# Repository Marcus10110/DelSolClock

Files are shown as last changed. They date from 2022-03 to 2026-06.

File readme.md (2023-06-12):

# Del Sol Clock

This is a project to replace the clock in my car with an ESP32 and a small display.

The replacement clock screen will display time, the currently playing music, and iOS notifications.

Bluetooth low energy is used to communicate with a phone.
Note, some services should support any BLE phone, for example the current time service. However the Apple Media Service and the notification service only support iOS.

## Features

### Apple Media Service

This displays the current playback information from the iPhone. It doesn't currently support playback controls (e.g. next/previous track).

[Apple Documentation.](https://developer.apple.com/library/archive/documentation/CoreBluetooth/Reference/AppleMediaService_Reference/Specification/Specification.html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)

Special thanks to the following examples. As far as I can tell, this hasn't been implemented using the [Arduino ESP32 board library](https://github.com/espressif/arduino-esp32) before.

- [James Hudson's Apple Notification Center Service](https://github.com/Smartphone-Companions/ESP32-ANCS-Notifications/blob/master/src/ancs_ble_client.cpp) This example finally showed how to solicit services using the Arduino ESP32 library, which is not built-in.
- [John Park's Adafruit Guide to the Apple Media Service Display](https://learn.adafruit.com/now-playing-bluetooth-apple-media-service-display/apple-music-service) This was the first working example I could find. Written in CircutPython.
- [Moddable's Apple Media Service example](https://github.com/Moddable-OpenSource/moddable/blob/6d7f33f8f318663bd5ba8d6ca6536443d42e68ea/modules/network/ble/ams-client/amsclient.js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) This was another good example, written in javascript.

### Current Time Service

This gets the current time.

[Current Time Service Documentation](https://www.bluetooth.com/specifications/specs/current-time-service-1-1/)

Note, the documentation is split over several PDFs. See CurrentTimeService.cpp for more documentation links.

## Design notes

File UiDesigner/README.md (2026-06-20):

# UiDesigner

Renders the Del Sol Clock's screens to BMP on the desktop, so screen UI can be
developed and reviewed without the ESP32.

The screen code is **shared** with the firmware: it lives in
`../firmware/lib/display/` and is compiled here against the real Adafruit GFX
library, so the rendered output is pixel-identical to the device.

## Render the screens

```powershell
pwsh -File tools/generate_on_save.ps1
```

Outputs to `out/`: one BMP per screen plus `all_screens.bmp` (a labeled grid of
all of them). Requires Visual Studio 2022 (C++ toolchain) and `ninja.exe` in
`.deps/`.

## Iterate

Open the **repo root** in VS Code and install the *Run on Save*
(`emeraldwalk.RunOnSave`) extension. Saving any screen source under
`firmware/lib/display/` or `runner/` auto-rebuilds and re-renders.

- Screen drawing code: `../firmware/lib/display/src/<group>_screen.cpp`
- Sample data each screen renders with: `../firmware/lib/display/src/demo_screens.cpp`
- BMP assets the screens reference: `data/`

## Manual build

```powershell
cmake -S . -B build -G "Visual Studio 17 2022" -A x64
cmake --build build --config Release --target render_screens
./build/Release/render_screens.exe   # run from this directory (resolves data/ + out/)
```

## Layout

- `runner/` — entry point + the desktop (file-backed) image loader
- `tools/` — build/configure/render scripts (`vsenv.ps1` sets up the VS env)
- `data/` — BMP assets for rendering
- `out/`, `build/`, `.deps/`, `reference/` — generated/local (gitignored)

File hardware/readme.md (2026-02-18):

# Hardware

The Del Sol Clock PCBs are designed to be direct replacements for the stock clock PCBs found in the original dash clock.

There are two PCBs in the clock housing. The front PCB, which contains pretty everything, and a rear PCB, which is largely responsible for the electrical connections to the car.

The two PCBs are designed with KiCad. The front PCB is located in the `./DelSolClock` directory, and the rear PCB is located in `./DelSolClock-Rear` directory.

## Front PCB

Schematic:

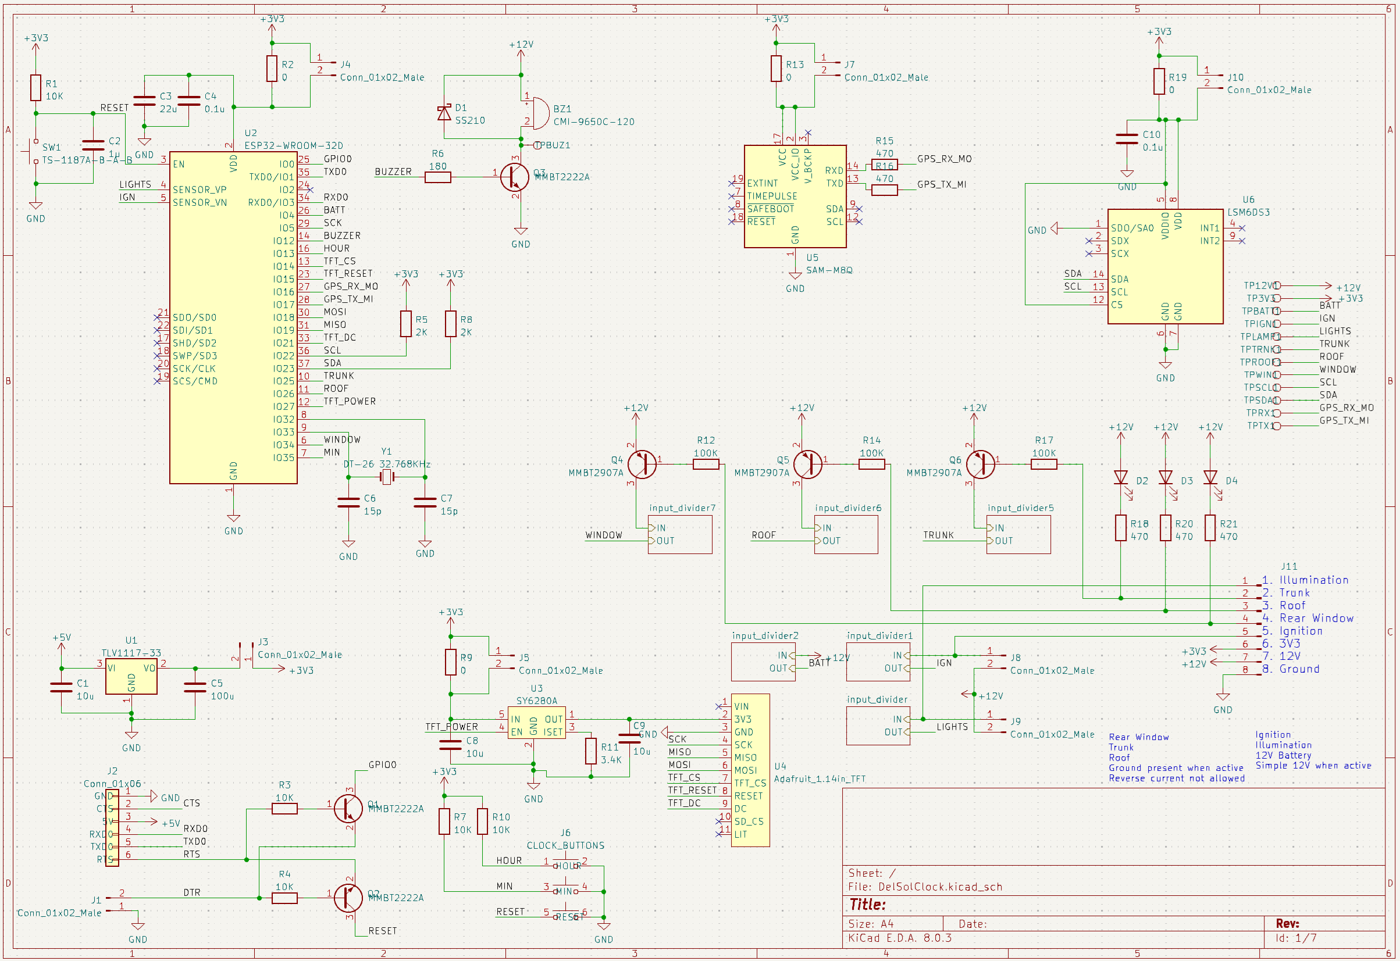
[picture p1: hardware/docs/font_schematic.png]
front schematic


Divider Circuit:

This divider circuit is used to shift the 12V signal down to 3.3V without engaging over voltage protection. It uses a ~3.6 volt Zener diode to clamp the voltage, which is preferred over regular rail clamps to prevent damage if the supply voltage is not present when a 12V input is applied.

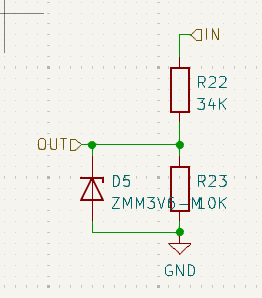
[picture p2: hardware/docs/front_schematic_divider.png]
voltage divider circuit


PCB:

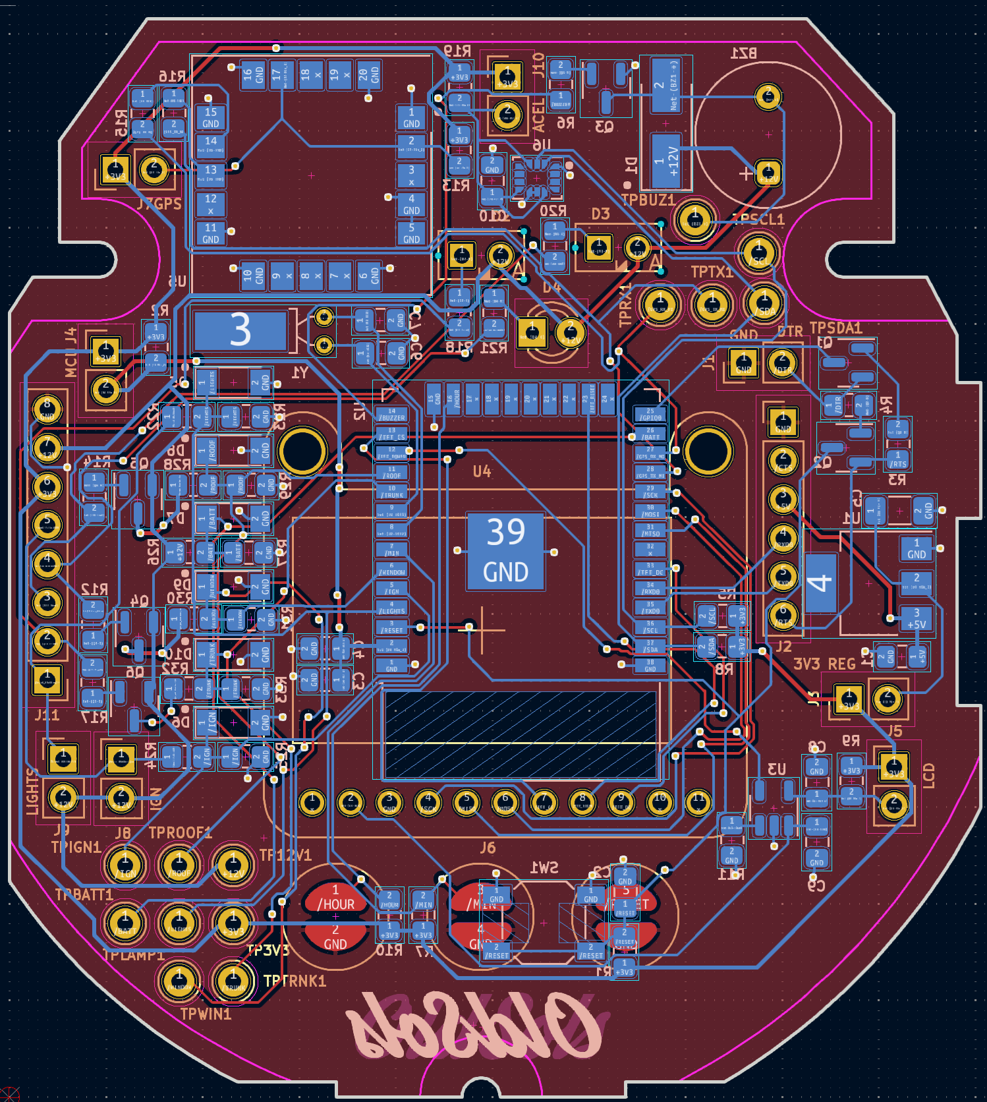
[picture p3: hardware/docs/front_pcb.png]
front PCB layout


## Rear PCB

The rear PCB contains a 12V to 3.3V buck converter module, to provide power to the front PCB, and routes all the car IO signals to the front PCB.

The front PCB is connected to the read PCB with a short 8 pin ribbon cable.

The rear PCB also contains diodes for the Trunk, Roof, and Window signals, to prevent backfeeding into the car's electrical system.

The following signals are provided by the car:

- 12V Power (battery, always hot)
- Ground
- Ignition (IGN)
- Rear Window
- Roof removed
- Trunk Open
- Dash Illumination (ILL)

Rear window, roof removed, and trunk open are open drain signals, which either float or get connected to ground when active. The stock dash clock contained indicator LEDs connected to these signals.

Ignition is also an active high signal, which is only high when the ignition is on. I think it floats when not active.

Dash illumination is connected to the dash's lights, which are dimmable, but only on when the headlights are on. This controlled the brightness of the original dash clock's display. When the headlights are off, the stock clock would run at max brightness.

Schematic:

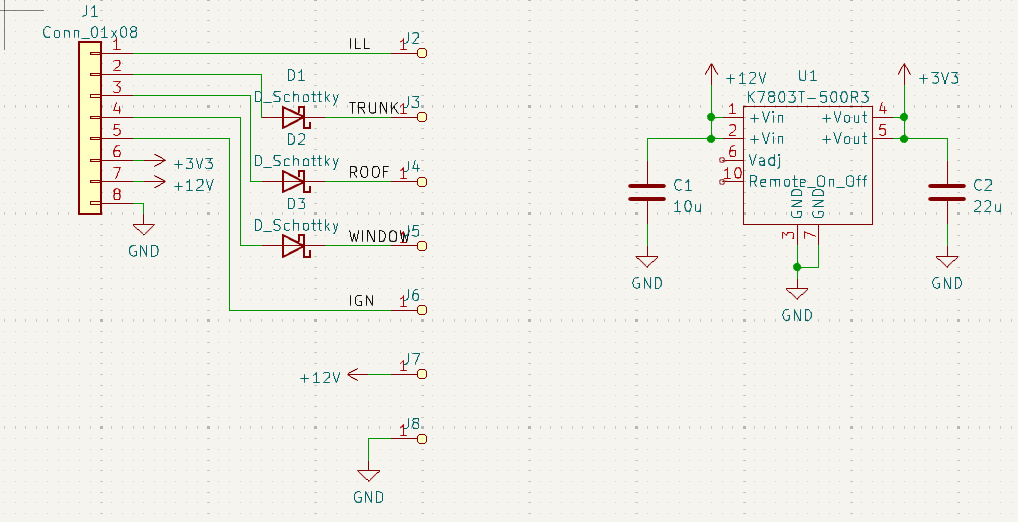
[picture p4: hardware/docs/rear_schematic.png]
rear schematic


PCB:

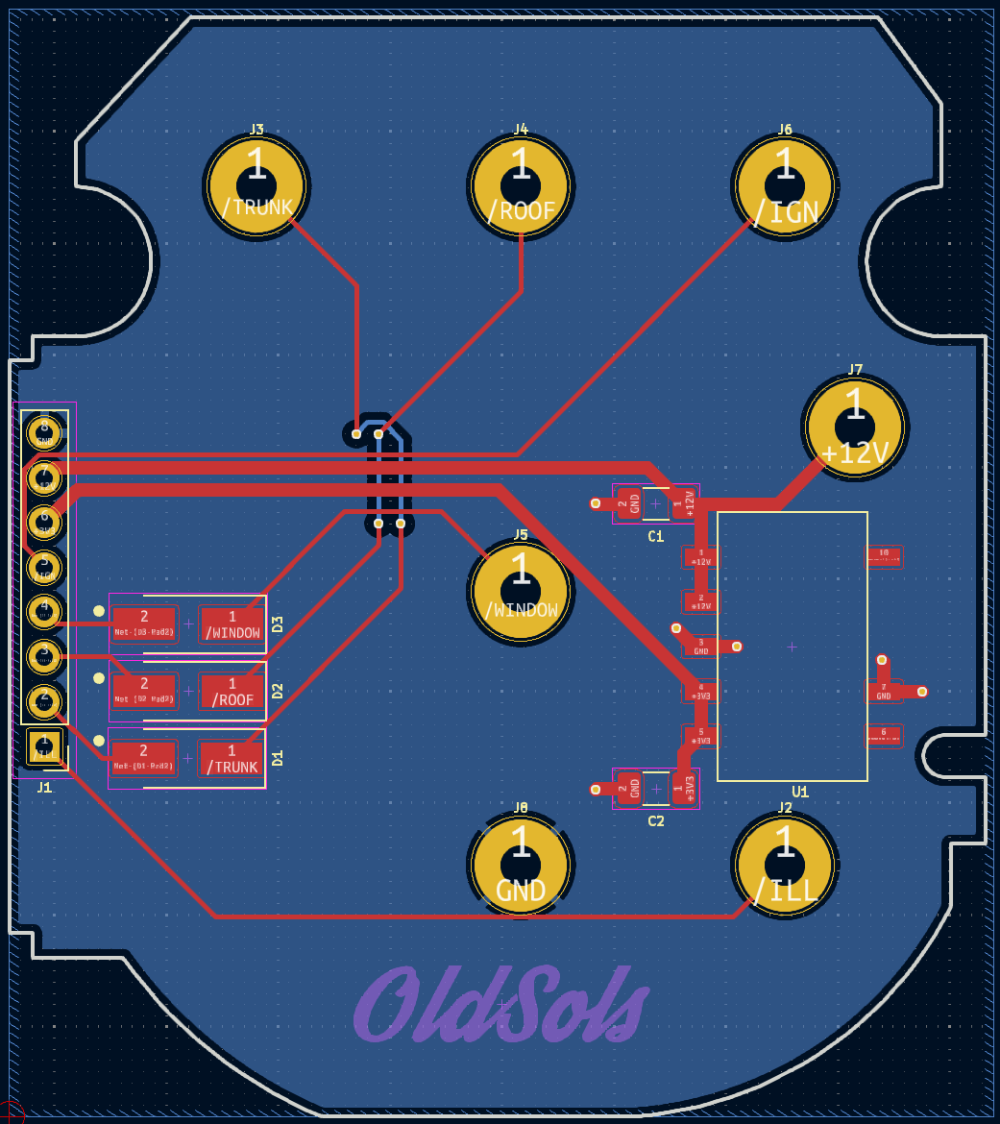
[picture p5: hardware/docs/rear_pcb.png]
rear PCB layout


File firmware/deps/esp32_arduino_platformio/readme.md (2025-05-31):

# Building ESP32 Arduino Libs for PlatformIO.

In order to use the 32Khz external crystal with the ESP32, you need to re-build the ESP32 Arduino libraries and bootloader with `CONFIG_RTC_CLK_SRC_EXT_CRYS` enabled.

## Background

Libraries & Tools involved:

- ESP32 IDF. This is the official development framework for the ESP32 chip from espressif.
- arduino-esp32. This is the Arduino core for the ESP32 chip, provided by espressif, which provides the Arduino API and libraries.
- esp32-arduino-lib-builder. This is a utility provided by espressif to build the Arduino libraries for the ESP32 chip, which is used by the ESP32 IDF.
- PlatformIO. This is a cross-platform IDE and build system for embedded systems, which supports the ESP32 and Arduino.

Unfortunately, at the time of writing, PlatformIO does not support the latest versions of arduino-esp32, so older versions are needed to use PlatformIO. If you're not using platformIO, you can likely use the latest versions of everything. Specifically, arduino-esp32 3.x is out now, but PlatformIO only supports 2.x.

## Version Details

[platformio/espressif32](https://registry.platformio.org/platforms/platformio/espressif32)

- This is the official PlatformIO platform for the ESP32, which includes the ESP32 IDF and arduino-esp32.
- Current version: 6.11.0
- uses arduino-esp32 2.0.17 (through framework-arduinoespressif32 v3.2, very confusing versioning here.)

[arduino-esp32](https://github.com/espressif/arduino-esp32)

- This is the official Arduino core for the ESP32 chip, provided by espressif.
- The latest is 3.2, however we're stuck on 2.0.17 for now.
- 2.0.17 depends on IDF 4.4.7

[esp-idf](https://github.com/espressif/esp-idf)

- This is the official development framework for the ESP32 chip from espressif.
- The latest version is 5.4.1, however we're stuck on 4.4.7 for now.

[esp32-arduino-lib-builder](https://github.com/espressif/esp32-arduino-lib-builder)

- This is a utility provided by espressif to build the Arduino libraries for the ESP32 chip, which is used by the ESP32 IDF.
- Releases on this repo appear to be informal. There are tags and branches for the matching IDF version.
- the latest release w/ tag is for IDF 5.5.
- We'll use the branch named `release/v4.4`.

## Build Summary

The basic build process is as follows. Assume a Linux environment, since we'll be building all of this in a Docker container.

Clone esp32-arduino-lib-builder, checkout branch `release/v4.4`.

Add a new defconfig file which has our flags to enable the external crystal.

Run `./build.sh` a few times, building the libraries and bootloader for our targets w/ our custom configuration, specifiying the IDF branch and the arduino branch.

TBD: fix up issues with dependencies that weren't pinned to a specific version and the latest is no longer compatible.

Copy the built libraries and bootloaders back out.

Create a new PlatformIO platform directory by combining the default one and our new builds.

Create a script to use our custom bootloader instead of the default one.

configure platformio.ini to use our custom platform.

## Build Steps

From windows, make sure you have docker installed and running.

Run `./host-build.ps1`

Wait forever. The build output will be placed in `./arduino-esp32`

## Installation

The build output needs to be combined with a stock copy of PlatformIO's espressif32 platform.

I recommend continuing in a subdirectory of your platformIO project, e.g. `deps/esp32_arduino_platformio`.

First, make sure you're project is already building using the stock PlatformIO espressif32 platform.

Then, copy the contents of the `HOME_DIR/.platformio/packages/framework-arduinoespressif32` to a new directory, e.g. `deps/esp32_arduino_platformio/framework-arduinoespressif32`.

Next, delete the existing esp32 directory `framework-arduinoespressif32/tools/sdk/esp32` and replace it with the new `.arduino-esp32/tools/sdk/esp32`

### Update your platformio.ini to use the new platform

In your `platformio.ini`, you should already have the platform set, something like this:

```ini
platform = espressif32@6.10.0
```

Below that, add the following block, with a path to you modified framework-arduinoespressif32 directory:

```ini
platform_packages =
	framework-arduinoespressif32@file:///path/to/deps/esp32_arduino_platformio/framework-arduinoespressif32/
```

At this point, you should be able to build and run your project. Your project should link against the newly build libraries.

However, clock configuration is done in the bootloader, so you still need to deploy the new bootloader for the clock source changes to take effect.

### Add a script to use the custom bootloader

Create a file called `replace_bootloader.py` in the root of your project with the following contents.

Be sure to update the path to the new bootloader.bin file. The new bootloader.bin was copied to `./arduino-esp32/bootloader/bootloader.bin` during the build process. You can leave it there or copy it somewhere inside your project.

```python
Import("env")

def override_bootloader_path(source, target, env):
    custom_bootloader = "esp32_images/bootloader.bin"

    flags = env["UPLOADERFLAGS"]
    for i, flag in enumerate(flags):
        if str(flag).endswith("bootloader.bin") and i > 0:
            print(f"⚙️ Replacing bootloader: {flags[i]} → {custom_bootloader}")
            flags[i] = custom_bootloader
            break

env.AddPreAction("upload", override_bootloader_path)
```

And in your `platformio.ini`, add the following line to the `[env]` section:

```ini
extra_scripts = pre:extra_replace_bootloader.py
```

### Testing & Troubleshooting

Somewhere in your project, run the following code:

```cpp
#include "soc/rtc.h"

auto src = rtc_clk_slow_freq_get();
auto hz = rtc_clk_slow_freq_get_hz();
LOG_TRACE( "RTC_SLOW_CLK frequency: %u Hz, source: %i", hz, src );
```

If the source is 0, that indicates the old 150 kHz internal RC oscillator is being used. If the source is 1, that indicates the 32kHz external crystal is being used. 2 indicates the 8MHz internal RC oscillator is being used.

If you see "1", then it's working!

If you see "0", there are two main possibilities:

1. Either the bootloader wasn't replaced, or it was replaced with one that wasn't configured properly.
2. The crystal failed to start up properly. There are a number of reasons this could happen. With the ESP32-WROOM-32E, a 2M to 5M ohm resistor is needed in parallel with the crystal. Please review the datasheet for your specific module to understand how the crystal should be connected.

## Additional customization and troubleshooting

You can set any ESP32 IDF flags you like by adding them to the `defconfig.rtc_ext_cry` file provided.

You can also launch the docker container interactively by running `./host-build.ps1 -Interactive`. This will re-use the same container over and over, so your changes will persist. Also, if you edit the `Dockerfile`, this command will delete your old container and create a new one with the new changes.

This is very useful to exploring menuconfig.

Because this uses IDF 4.4, some of the configuration options are different than what you may see in the latest online documentation. Take a look at `arduino-esp32/tools/sdk/esp32/sdkconfig` in the output to see what options are available, and if they were set or not by default.

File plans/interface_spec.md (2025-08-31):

# Del Sol Clock UI Product Specification

The Del Sol Clock is an accessory for the 90s Honda Del Sol, a 2 seat convertible.

The car comes standard with a in-dash clock capable of displaying 12 hour time.

The Del Sol Clock project is a hardware drop-in replacement for the in-dash clock.

This project replaces the 7-segment display with a 1.1 inch full color display, 240x136 pixels.

The display is driven by a C++ application running on an ESP32.

# Functions

The application has access to a number of inputs, which are used by its features.

## Inputs

- Headlights on/off.
- Ignition on/off
- rear window down
- trunk open
- convertible roof down
- car battery voltage (analog)
- GPS module (speed, etc.)
- 6DoF inertial measurement unit

# Screens (Essentially the same as pages)

The Del Sol Clock project has several screens:

## Splash Screen

When the car turns on, the splash screen is shown for several seconds. It shows a picture of a white Honda Del Sol, and the "OldSols" logo.

## Default Screen (Time Screen)

The default screen. This screen displays the current time in large type, using a font that looks like a 7 segment display.

It also shows AM or PM in small print.

Across the bottom, it shows the name of the current song that's playing, if one is playing.

In the top left, it shows the current speed.

In the top right, there is a head lights on/off indicator.

If bluetooth is lost, a red bluetooth icon appears on the right.

## Lights On Alarm Screen

This screen is only shown when the ignition is off, but the headlights are on.
It features a large headlights icon, and the text "LIGHTS ON"

## Bluetooth Discoverable Screen

If the device hasn't been paired to a phone yet, instead of showing the default screen, it shows the bluetooth pairing screen.
This screen shows the name of the device, "DelSolClock" and informs the user that it's bluetooth discoverable. Once connected, the default screen is displayed. This screen is only shown on boot if no device is connected. If the device disconnects, a red bluetooth icon is added to the default screen, but it does not return to the discoverable screen.

## Navigation Screen

The navigation screen shows the next step in turn-by-turn navigation.

Typical steps are "Turn left onto <street name>", "Keep right, follow signs for <> and merge onto <>", etc.

The appropriate icon is also shown.

## Notification Screen

This screen just shows the latest iPhone notification in large text and the previous 2 notifications in small text across the bottom.

## Firmware Update Screen

This screen is not selectable from the device. however if the paired mobile phone is connected, and initiates a firmware update, this screen pops up and shows a progress bar for the firmware update. All it shows is the label "Firmware Update" and the progress bar.

## Quarter Mile Timer

This screen is used to allow the driver to time their quarter mile.

It's manually initiated and has 4 phases.

All four phases show the title "Quarter Mile"

The phases are:

Phase 1: "Press M to Start". The user presses the minute button on the clock to start the quarter mile timer.
Phase 2: "Waiting for Launch..." This screen shows the forward direction accelerometer data (0g when stationary.) The quarter mile timer will automatically activate when sufficient G forces are detected. It simply shows the current value (0.0g, etc.)
Phase 3: The record phase. This screen shows the time elapsed since the start, the current forward G force, and the distanced traveled (in miles) Below that is a progress bar, displaying the distance out of 0.25 miles traveled.
Phase 4: The result phase. This screen shows the total quarter mile time, the 0-60 mph time (if 60 mph was reached, otherwise "--"), the max speed, and the max acceleration measured.

## Status page

This page shows several key/value pairs in a grid. Latitude, Longitude, Speed, Heading, and Battery Voltage to start with.

# Interface

The user can press the "H" (hour) button to cycle between the screens. If the current screen supports interaction, the "M" (minute) button is used. The clock as a reset button, which acts as a full hardware reset.

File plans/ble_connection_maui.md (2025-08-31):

# BLE Connection Architecture for MAUI App (Revised)

## Overview
Design a clean, simple BLE connection architecture for the Del Sol Clock MAUI application. The old Xamarin implementation provides insights into the device interface. This revised architecture prioritizes simplicity and explicit user control over automatic behavior.

## Key Observations from Legacy Implementation
- Uses Plugin.BLE library (same as new project: v3.2.0-beta.1)
- Device uses multiple services (Vehicle, Firmware, Location, Navigation)  
- Status characteristic provides comma-separated boolean values: "0,0,0,1,1"
- Battery characteristic provides 4-byte float value
- Firmware update uses 512-byte chunks with response validation
- BLE auto-reconnection is unreliable across platforms - needs explicit management
- Uses characteristic notifications for real-time updates

## Architecture Design Principles

### 1. **Explicit Over Automatic**
- UI controls device discovery and connection
- No surprise auto-connections
- Clear user feedback for all operations

### 2. **Simple Over Complex** 
- Concrete classes instead of interfaces where possible
- Automatic notification management (start on connect, stop on disconnect)
- Minimal API surface

### 3. **User-Controlled Discovery**
- Separate discovery from connection
- Show available devices before connection attempt
- Support manual refresh of device list

## Core Classes

#### 1. `DelSolDevice` - Main Class (Simplified)
```csharp
public class DelSolDevice : IDisposable
{
    private BleConnectionManager _connectionManager;
    private VehicleService _vehicleService;
    private FirmwareService _firmwareService;
    private readonly ILogger<DelSolDevice> _logger;
    
    // Public API
    public bool IsConnected => _connectionManager?.IsConnected ?? false;
    public string ConnectedDeviceName => _connectionManager?.ConnectedDeviceName;
    public string FirmwareVersion { get; private set; }
    
    // Events
    public event EventHandler<ConnectionStatusChangedEventArgs> ConnectionStatusChanged;
    public event EventHandler<VehicleStatusChangedEventArgs> VehicleStatusChanged;
    public event EventHandler<BatteryStatusChangedEventArgs> BatteryStatusChanged;
    public event EventHandler<FirmwareUpdateProgressEventArgs> FirmwareUpdateProgress;
    
    // Methods
    public async Task<bool> InitializeAsync();
    public async Task<List<DiscoveredDevice>> ScanForDevicesAsync(TimeSpan timeout = default);
    public async Task<List<DiscoveredDevice>> GetKnownDevicesAsync();
    public async Task<bool> ConnectAsync(DiscoveredDevice device);
    public async Task DisconnectAsync();
    public async Task<VehicleStatus> GetVehicleStatusAsync();
    public async Task<float> GetBatteryVoltageAsync();
    public async Task<bool> UpdateFirmwareAsync(Stream firmwareStream, CancellationToken cancellationToken = default);
    
    void Dispose();
}
```

#### 2. `BleConnectionManager` - Connection Management
```csharp
public class BleConnectionManager : IDisposable
{
    private IAdapter _adapter;
    private IDevice _connectedDevice;
    private readonly ILogger<BleConnectionManager> _logger;
    
    public bool IsConnected => _connectedDevice?.State == DeviceState.Connected;
    public string ConnectedDeviceName => _connectedDevice?.Name;
    public IDevice ConnectedDevice => _connectedDevice;
    
    public event EventHandler<ConnectionStatusChangedEventArgs> ConnectionStatusChanged;
    
    public async Task<bool> InitializeAsync()
    {
        // Check BLE permissions for current platform
        // Initialize Plugin.BLE adapter
        // Subscribe to BLE state changes
        // Set up device connection/disconnection event handlers
    }
    
    public async Task<List<DiscoveredDevice>> ScanForDevicesAsync(Guid serviceId, TimeSpan timeout)
    {
        // Scan for devices advertising the specified service
        // Return list of discovered devices with metadata
        // Don't automatically connect - let UI decide
    }
    
    public async Task<List<DiscoveredDevice>> GetKnownDevicesAsync(Guid serviceId)
    {
        // Get system connected/paired devices with specific service
        // Check which ones are currently in range
        // Return list with connection status
    }
    
    public async Task<bool> ConnectAsync(DiscoveredDevice device)
    {
        // Connect to specific device
        // Validate connection and required services
        // Set up connection monitoring
    }
    
    public async Task DisconnectAsync()
    {
        // Cleanly disconnect current device
        // Clean up resources
    }
    
    public async Task<IService> GetServiceAsync(Guid serviceId)
    {
        // Get service from connected device
        // Throw if not connected or service not found
    }
}
```

#### 3. `DiscoveredDevice` - Device Information
```csharp
public class DiscoveredDevice
{
    public string Name { get; set; }
    public string Id { get; set; }
    public Guid DeviceId { get; set; }
    public bool IsKnownDevice { get; set; }  // Previously paired
    public int SignalStrength { get; set; }
    public DateTime LastSeen { get; set; }
    
    // Internal reference to Plugin.BLE device
    internal IDevice BleDevice { get; set; }
    
    public override string ToString() => $"{Name} ({(IsKnownDevice ? "Known" : "New")})";
}
```

#### 4. `VehicleService` - Vehicle Data Management
```csharp
public class VehicleService : IDisposable
{
    private ICharacteristic _statusCharacteristic;
    private ICharacteristic _batteryCharacteristic;
    private readonly ILogger<VehicleService> _logger;
    
    public event EventHandler<VehicleStatusChangedEventArgs> StatusChanged;
    public event EventHandler<BatteryStatusChangedEventArgs> BatteryChanged;
    
    public async Task<bool> InitializeAsync(IDevice device)
    {
        // Get vehicle service from device
        // Discover status and battery characteristics
        // Automatically start notifications (simplified)
        await _statusCharacteristic.StartUpdatesAsync();
        // Set up event handlers
    }
    
    public async Task<VehicleStatus> GetStatusAsync()
    {
        if (_statusCharacteristic == null) return null;
        
        // Read current value from characteristic
        var value = await _statusCharacteristic.ReadAsync();
        return ParseStatusBytes(value);
    }
    
    public async Task<float> GetBatteryVoltageAsync()
    {
        if (_batteryCharacteristic == null) return 0f;
        
        // Read 4-byte float from characteristic
        var bytes = await _batteryCharacteristic.ReadAsync();
        return BitConverter.ToSingle(bytes, 0);
    }
    
    private VehicleStatus ParseStatusBytes(byte[] value)
    {
        // Parse "0,0,0,1,1" format into VehicleStatus
        var statusString = Encoding.UTF8.GetString(value);
        var parts = statusString.Split(',');
        
        if (parts.Length != 5) return null;
        
        return new VehicleStatus
        {
            RearWindowDown = parts[0] == "1",
            TrunkOpen = parts[1] == "1", 
            ConvertibleRoofDown = parts[2] == "1",
            IgnitionOn = parts[3] == "1",
            HeadlightsOn = parts[4] == "1",
            LastUpdated = DateTime.Now
        };
    }
    
    private void OnStatusUpdated(object sender, CharacteristicUpdatedEventArgs e)
    {
        var status = ParseStatusBytes(e.Characteristic.Value);
        StatusChanged?.Invoke(this, new VehicleStatusChangedEventArgs { Status = status });
    }
    
    public void Dispose()
    {
        // Automatically stop notifications and clean up
        if (_statusCharacteristic != null)
        {
            _statusCharacteristic.ValueUpdated -= OnStatusUpdated;
            _statusCharacteristic.StopUpdatesAsync().Wait();
        }
    }
}
```

#### 5. `FirmwareService` - Firmware Management  
```csharp
public class FirmwareService : IDisposable
{
    private ICharacteristic _writeCharacteristic;
    private ICharacteristic _versionCharacteristic;
    private TaskCompletionSource<string> _writeResponseTask;
    private readonly ILogger<FirmwareService> _logger;
    
    public event EventHandler<FirmwareUpdateProgressEventArgs> UpdateProgressChanged;
    
    public async Task<bool> InitializeAsync(IDevice device)
    {
        // Get firmware service
        // Discover characteristics
        // Set up write response notifications
        await _writeCharacteristic.StartUpdatesAsync();
    }
    
    public async Task<string> GetVersionAsync()
    {
        if (_versionCharacteristic == null) return "Unknown";
        
        var bytes = await _versionCharacteristic.ReadAsync();
        return Encoding.UTF8.GetString(bytes);
    }
    
    public async Task<bool> UpdateFirmwareAsync(Stream firmwareStream, CancellationToken cancellationToken = default)
    {
        const int chunkSize = 512;
        var buffer = new byte[chunkSize];
        long totalBytes = firmwareStream.Length;
        long bytesWritten = 0;
        var startTime = DateTime.Now;
        
        while (!cancellationToken.IsCancellationRequested)
        {
            int bytesRead = await firmwareStream.ReadAsync(buffer, 0, chunkSize, cancellationToken);
            if (bytesRead == 0) break;
            
            // Prepare chunk to write
            var chunk = new byte[bytesRead];
            Array.Copy(buffer, chunk, bytesRead);
            
            // Write and wait for response
            var response = await WriteChunkAndWaitForResponseAsync(chunk, TimeSpan.FromSeconds(10));
            bytesWritten += bytesRead;
            
            // Calculate and report progress
            var progress = new FirmwareUpdateProgressEventArgs
            {
                PercentComplete = (double)bytesWritten / totalBytes * 100,
                SpeedBytesPerSecond = bytesWritten / (DateTime.Now - startTime).TotalSeconds,
                EstimatedTimeRemaining = TimeSpan.FromSeconds((totalBytes - bytesWritten) / 
                    (bytesWritten / (DateTime.Now - startTime).TotalSeconds))
            };
            UpdateProgressChanged?.Invoke(this, progress);
            
            // Handle response
            if (response == "success") return true;
            if (response == "error") return false;
            if (response != "continue") 
                throw new Exception($"Unexpected response: {response}");
        }
        
        // Handle edge case: exact 512-byte multiple needs zero-length write
        if (totalBytes % chunkSize == 0)
        {
            var finalResponse = await WriteChunkAndWaitForResponseAsync(new byte[0], TimeSpan.FromSeconds(10));
            return finalResponse == "success";
        }
        
        return false;
    }
    
    private async Task<string> WriteChunkAndWaitForResponseAsync(byte[] chunk, TimeSpan timeout)
    {
        _writeResponseTask = new TaskCompletionSource<string>();
        
        var success = await _writeCharacteristic.WriteAsync(chunk);
        if (!success) throw new Exception("Write failed");
        
        using (var cts = new CancellationTokenSource(timeout))
        {
            cts.Token.Register(() => _writeResponseTask.TrySetException(new TimeoutException()));
            return await _writeResponseTask.Task;
        }
    }
    
    private void OnWriteResponseReceived(object sender, CharacteristicUpdatedEventArgs e)
    {
        var response = Encoding.UTF8.GetString(e.Characteristic.Value);
        _writeResponseTask?.TrySetResult(response);
    }
    
    public void Dispose()
    {
        if (_writeCharacteristic != null)
        {
            _writeCharacteristic.ValueUpdated -= OnWriteResponseReceived;
            _writeCharacteristic.StopUpdatesAsync().Wait();
        }
    }
}
```

### Data Models

#### 6. `VehicleStatus` - Vehicle State Data
```csharp
public class VehicleStatus
{
    public bool RearWindowDown { get; set; }
    public bool TrunkOpen { get; set; }
    public bool ConvertibleRoofDown { get; set; }
    public bool IgnitionOn { get; set; }
    public bool HeadlightsOn { get; set; }
    
    public DateTime LastUpdated { get; set; }
    
    public override string ToString()
    {
        var items = new List<string>();
        items.Add($"Window: {(RearWindowDown ? "DOWN" : "UP")}");
        items.Add($"Trunk: {(TrunkOpen ? "OPEN" : "CLOSED")}");
        items.Add($"Roof: {(ConvertibleRoofDown ? "DOWN" : "UP")}");
        items.Add($"Ignition: {(IgnitionOn ? "ON" : "OFF")}");
        items.Add($"Lights: {(HeadlightsOn ? "ON" : "OFF")}");
        return string.Join(", ", items);
    }
}
```

#### 7. Event Args Classes
```csharp
public class ConnectionStatusChangedEventArgs : EventArgs
{
    public bool IsConnected { get; set; }
    public string DeviceName { get; set; }
    public string ErrorMessage { get; set; }
}

public class VehicleStatusChangedEventArgs : EventArgs
{
    public VehicleStatus Status { get; set; }
}

public class BatteryStatusChangedEventArgs : EventArgs
{
    public float Voltage { get; set; }
    public DateTime Timestamp { get; set; }
}

public class FirmwareUpdateProgressEventArgs : EventArgs
{
    public double PercentComplete { get; set; }
    public double SpeedBytesPerSecond { get; set; }
    public TimeSpan EstimatedTimeRemaining { get; set; }
    public bool IsCompleted { get; set; }
    public string ErrorMessage { get; set; }
}
```

## Implementation Strategy

### Phase 1.1: BLE Service Implementation (3-4 days)

**Day 1: Core Infrastructure**
1. Implement `BleConnectionManager` with basic Plugin.BLE integration
2. Add permission handling for Windows/Android/iOS
3. Implement explicit device discovery (scan and known devices)
4. Add proper disposal and cleanup

**Day 2: Connection Management**  
1. Implement user-controlled connection to specific devices
2. Add connection state management and error handling
3. Implement service discovery and validation
4. Add comprehensive logging

**Day 3: Service Layer Foundation**
1. Implement `VehicleService` basic structure
2. Add characteristic discovery and initialization
3. Implement basic read operations for status and battery
4. Add automatic notification subscription logic

**Day 4: Integration and Testing**
1. Integrate all components into `DelSolDevice`
2. Add comprehensive error handling
3. Test connection/disconnection scenarios
4. Validate service discovery and characteristic access

### Phase 1.2: Characteristic Reading Infrastructure (2-3 days)

**Day 1: Status Characteristic**
1. Implement status string parsing ("0,0,0,1,1" format)
2. Add notification handling for real-time updates
3. Implement `VehicleStatus` data model
4. Add status change event propagation

**Day 2: Battery and Firmware Characteristics**
1. Implement battery voltage reading (4-byte float)
2. Add firmware version reading
3. Implement proper data conversion and validation
4. Add battery change notifications (if available)

**Day 3: Event System and Polish**
1. Implement comprehensive event system
2. Add proper error handling for all characteristic operations
3. Implement data validation and error recovery
4. Test with actual device if available

## Key Design Decisions (Revised)

### 1. **Explicit User Control**
- `BleConnectionManager` separates discovery from connection
- UI decides when to scan, what devices to show, and when to connect
- No automatic or surprise connections

### 2. **Simplified Architecture**  
- Concrete classes instead of interfaces where appropriate
- Automatic notification management (start on initialize, stop on dispose)
- Minimal API surface reduces complexity

### 3. **Event-Driven Updates**
- Real-time updates via events rather than polling
- Allows UI to react immediately to device changes
- Simple event model with clear event args

### 4. **Resource Management**
- Proper IDisposable implementation throughout
- Automatic cleanup of BLE resources and event subscriptions
- Memory-efficient stream handling for firmware updates

### 5. **User-Centered Discovery**
- Separate methods for scanning vs. known devices
- Rich device information (name, signal strength, known status)
- Manual refresh model supports UI-controlled periodic updates

## Constants and Configuration

```csharp
public static class DelSolConstants
{
    // Service UUIDs
    public static readonly Guid VehicleServiceGuid = new("8fb88487-73cf-4cce-b495-505a4b54b802");
    public static readonly Guid FirmwareServiceGuid = new("69da0f2b-43a4-4c2a-b01d-0f11564c732b");
    public static readonly Guid LocationServiceGuid = new("61d33c70-e3cd-4b31-90d8-a6e14162fffd");
    public static readonly Guid NavigationServiceGuid = new("77f5d2b5-efa1-4d55-b14a-cc92b72708a0");
    
    // Vehicle Service Characteristics
    public static readonly Guid StatusCharacteristicGuid = new("40d527f5-3204-44a2-a4ee-d8d3c16f970e");
    public static readonly Guid BatteryCharacteristicGuid = new("5c258bb8-91fc-43bb-8944-b83d0edc9b43");
    
    // Firmware Service Characteristics  
    public static readonly Guid FirmwareWriteCharacteristicGuid = new("7efc013a-37b7-44da-8e1c-06e28256d83b");
    public static readonly Guid FirmwareVersionCharacteristicGuid = new("a5c0d67a-9576-47ea-85c6-0347f8473cf3");
    
    // Configuration
    public const int FirmwareChunkSize = 512;
    public const int DefaultTimeoutSeconds = 10;
    public static readonly TimeSpan DefaultScanTimeout = TimeSpan.FromSeconds(10);
}
```

## Simplified Dependency Injection Setup

```csharp
// In MauiProgram.cs - Simplified without interfaces
public static MauiApp CreateMauiApp()
{
    var builder = MauiApp.CreateBuilder();
    builder
        .UseMauiApp<App>()
        .ConfigureFonts(fonts => fonts.AddFont("OpenSans-Regular.ttf", "OpenSansRegular"));

    // Register BLE services (concrete classes)
    builder.Services.AddSingleton<DelSolDevice>();
    
    // Register pages
    builder.Services.AddTransient<StatusPage>();
    builder.Services.AddTransient<UpdatePage>();
    builder.Services.AddTransient<LogPage>();
    
    return builder.Build();
}
```

## Example UI Usage Pattern

```csharp
public partial class StatusPage : ContentPage
{
    private readonly DelSolDevice _delSolDevice;
    
    public StatusPage(DelSolDevice delSolDevice)
    {
        InitializeComponent();
        _delSolDevice = delSolDevice;
        _delSolDevice.VehicleStatusChanged += OnVehicleStatusChanged;
        _delSolDevice.ConnectionStatusChanged += OnConnectionStatusChanged;
    }
    
    private async void OnScanButtonClicked(object sender, EventArgs e)
    {
        try 
        {
            ScanButton.IsEnabled = false;
            StatusLabel.Text = "Scanning...";
            
            // Show known devices first
            var knownDevices = await _delSolDevice.GetKnownDevicesAsync();
            if (knownDevices.Any())
            {
                DeviceList.ItemsSource = knownDevices;
                return;
            }
            
            // If no known devices, scan for new ones
            var discoveredDevices = await _delSolDevice.ScanForDevicesAsync(TimeSpan.FromSeconds(10));
            DeviceList.ItemsSource = discoveredDevices;
        }
        finally
        {
            ScanButton.IsEnabled = true;
            StatusLabel.Text = "Ready";
        }
    }
    
    private async void OnConnectButtonClicked(object sender, EventArgs e)
    {
        if (sender is Button button && button.CommandParameter is DiscoveredDevice device)
        {
            var success = await _delSolDevice.ConnectAsync(device);
            if (!success)
            {
                await DisplayAlert("Error", "Failed to connect to device", "OK");
            }
        }
    }
}
```

This revised architecture prioritizes simplicity and user control while maintaining clean separation of concerns and extensibility for future features.

## Recommended File/Folder Structure

```
DelSolClockAppMaui/
├── Services/
│   ├── DelSolDevice.cs                    // Main orchestration class
│   ├── BleConnectionManager.cs            // BLE connection management
│   ├── VehicleService.cs                  // Vehicle status & battery
│   ├── FirmwareService.cs                 // Firmware updates
│   └── DelSolConstants.cs                 // UUIDs and configuration
├── Models/
│   ├── VehicleStatus.cs                   // Vehicle state data
│   ├── DiscoveredDevice.cs                // Device discovery info
│   └── EventArgs/
│       ├── ConnectionStatusChangedEventArgs.cs
│       ├── VehicleStatusChangedEventArgs.cs
│       ├── BatteryStatusChangedEventArgs.cs
│       └── FirmwareUpdateProgressEventArgs.cs
├── Pages/
│   ├── StatusPage.xaml                    // Status display UI
│   ├── StatusPage.xaml.cs                 // Status page logic
│   ├── UpdatePage.xaml                    // Firmware update UI
│   ├── UpdatePage.xaml.cs                 // Firmware update logic
│   ├── LogPage.xaml                       // Logs display UI
│   └── LogPage.xaml.cs                    // Logs page logic
├── Components/                            // Reusable UI components
│   ├── StatusItem.xaml                    // Individual status display
│   ├── StatusItem.xaml.cs
│   ├── DeviceListItem.xaml                // Device list entry (new)
│   ├── DeviceListItem.xaml.cs
│   ├── UpdateItem.xaml                    // Firmware release item
│   └── UpdateItem.xaml.cs
├── ViewModels/                            // If using MVVM pattern
│   ├── StatusItemData.cs                  // Existing status item data
│   └── UpdateItemData.cs                  // Existing update item data
├── Resources/
│   └── Images/
│       └── icons/                         // BLE and status icons
│           ├── bluetooth.svg
│           ├── bluetooth_connected.svg    // New - connected state
│           ├── bluetooth_disconnected.svg // New - disconnected state
│           ├── battery.svg                // New - battery icon
│           ├── headlights_on.svg          // Existing
│           └── ...                        // Other status icons
├── Platforms/                             // Platform-specific code
│   ├── Android/
│   │   └── BluetoothPermissions.cs        // Android BLE permissions
│   ├── iOS/
│   │   └── BluetoothPermissions.cs        // iOS BLE permissions
│   └── Windows/
│       └── BluetoothPermissions.cs        // Windows BLE permissions
├── AppShell.xaml                          // Navigation shell
├── AppShell.xaml.cs
├── MauiProgram.cs                         // DI and logging setup
└── DelSolClockAppMaui.csproj             // Project file with Plugin.BLE
```

## Implementation Order by File

### Phase 1.1 Files (Days 1-4):

**Day 1: Core Infrastructure**
1. `Services/DelSolConstants.cs` - UUIDs and configuration constants
2. `Models/DiscoveredDevice.cs` - Device discovery data model
3. `Models/EventArgs/ConnectionStatusChangedEventArgs.cs` - Connection events
4. `Services/BleConnectionManager.cs` - Basic BLE connection (discovery/connect methods)

**Day 2: Connection Management**
1. Complete `Services/BleConnectionManager.cs` - Add error handling, logging
2. `Platforms/*/BluetoothPermissions.cs` - Platform-specific permissions (if needed)
3. Test basic device discovery and connection

**Day 3: Service Layer**
1. `Models/VehicleStatus.cs` - Vehicle status data model
2. `Models/EventArgs/VehicleStatusChangedEventArgs.cs` - Vehicle events
3. `Models/EventArgs/BatteryStatusChangedEventArgs.cs` - Battery events
4. `Services/VehicleService.cs` - Vehicle characteristic handling

**Day 4: Integration**
1. `Services/DelSolDevice.cs` - Main orchestration class
2. Update `MauiProgram.cs` - Add DI registration and logging
3. Integration testing

### Phase 1.2 Files (Days 5-7):

**Day 5: Status Implementation**
1. Complete parsing logic in `Services/VehicleService.cs`
2. Test status characteristic reading and notifications
3. Update `Pages/StatusPage.xaml.cs` - Connect to new BLE service

**Day 6: Firmware Characteristics**
1. `Models/EventArgs/FirmwareUpdateProgressEventArgs.cs` - Firmware events
2. `Services/FirmwareService.cs` - Basic firmware version reading
3. Update `Pages/UpdatePage.xaml.cs` - Connect to new BLE service

**Day 7: Polish**
1. Add comprehensive error handling across all services
2. Test event propagation and UI updates
3. Add any missing logging and validation

## File Size Estimates

- **Small files** (< 100 lines): EventArgs classes, Models, Constants
- **Medium files** (100-300 lines): BleConnectionManager, VehicleService, Page code-behind
- **Large files** (300+ lines): DelSolDevice (orchestration), FirmwareService (complex update logic)

## Notes

- **Existing files to modify**: `MauiProgram.cs`, `StatusPage.xaml.cs`, `UpdatePage.xaml.cs`
- **Platform-specific files**: Only create if Plugin.BLE doesn't handle permissions automatically
- **ViewModels folder**: Keep existing files, may add more if moving to full MVVM pattern
- **Components folder**: Existing UI components, may add DeviceListItem for device discovery UI

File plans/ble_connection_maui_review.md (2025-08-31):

This is a general software architecture question: Why does the IDelSolDevice interface exist? What value does it have, when compared to just having the concrete implementation?
Same goes for other interfaces.

BleConnectionManager ergonomics: it seems like this searches for potential devices and connects to the first one. I would like to break this up a bit - instead, for discovery: if we're not already connected to a device, then I'd like the UI to show if there is a matching device in range or not. If there is, the UI should allow the user to click a button to pair it. The pairing operation might still fail, but this way the user knows what to expect before they try pairing. When we don't have a device connected, it would be nice to either auto-refresh this or allow the user to refresh manually. Perhaps we only need to support manual refresh at this level, and a higher level could use a timer to refresh periodically?

If a already paired device was disconnected, and then appears again, will the phone/PC automatically reconnect to it? If so, do we need the ConnectToKnownDeviceAsync function? If not, then like above, if the app is not connected, and a known device is in range, it would be nice to show that before the user initiates a connection.

For StartStatusNotificationsAsync and StopStatusNotificationsAsync, do these need to be explicit methods, or could we just always subscribe when we create the service, and unsubscribe when the service is disposed?

I am not familiar with .NET maui development. Could you explain the purpose of registering these managers with the MauiApp builder?

My current application does not call builder.Services.AddTransient either. what does this do?

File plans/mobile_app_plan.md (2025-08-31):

I am working on a .NET maui application that I want to target windows desktop, iOS and Android.

This is a companion app for a bluetooth LE device I am working on, which is a small display installed in a car (specifically a Honda Del Sol).

The app should be simple, and have the following features.

- Bluetooth LE discovery and pairing. The app should have a feature that allows you to scan for bluetooth LE devices and connect. The device advertises a specific service ID, and we can filter for devices that offer this service.

- Current status Screen.
  This should show if our device is currently paired or not. If it is paired, it should show values from a few characteristics that the device exposes.
  The values it should show are:

  - Battery voltage
  - Rear Window up or down
  - Trunk open or closed
  - Convertible roof up or down
  - Car ignition on or off
  - Headlights on or off

  This screen may be extended later to include values like current screen, longitude and latitude, current acceleration data (XYZ) and more.

- Firmware screen.
  This screen is used for firmware updates. Firmware updates are published as releases to the a public github repository. This page uses the github API to list all releases.
  When the user selects a release, they can install it (if the device is connected over BLE) or they can click a button to open the release page in their default browser. (outside of the app)
  For each release, the release title, description, and creation date are shown.
  If the device is currently paired, the current FW version should be shown at the top. Also, if the FW version matches any entries in the list of available firmware, that item should be tagged as "installed"

When a firmware update is initiated, the associated asset file is downloaded into memory, and written to a specific BLE characteristic 512 bytes at a time. The progress is reported with a progress bar. A cancel button allows the operation to be aborted.
If the FW happens to be an exact multiple of 512 bytes, then the app needs to write a zero-length value at the end to trigger the FW update. otherwise the update triggers on the final, non-512 byte write.
The characteristic updates itself after each write, and will contain the string "success", "continue", or "error" after each buffer is received by the device. The app continues to upload if it sees "continue", and reports success or failure once one of the other values appears. Also, if the entire firmware image is uploaded but the final response is still "continue", an error is reported to the user. Also if an upload times out, the operation is canceled and an error is reported. If the user cancels, no more messages are sent to the device. (likely to change later)

- Logs screen.

The device generates logs. Ideally, if the app is connected to the device, the app should be able to show the logs.
The firmware does not currently support this, but we could easily add either (A) a circular buffer on the device that the app can read from, or (B) a characteristic that notifies when new logs are added, or something else. Recomendations welcome.
This screen should show logs, which look like this:

```
[7786] [T] [src/main.cpp:106] setup, bluetooth service...
[7786] [D] [src/bluetooth.cpp:365] connected!
```

This screen should have some way to save these logs to view later. it could be as simple as just having a save button that allows the user to pick a file name (default should be human readable date & time stamp) and save it. Doesn't really matter where as long as the file can be found later when say attaching it to an email.

I have a new .NET MAUI application in the DelSolClockAppMaui directory, and an older Xamarin app in the DelSolClockApp directory. The firmware is in the firmware directory.

The new application is bare bones and has little to no functionality implemented yet.

The old app is considerably more complete, but was never finished.

The scope of this project is to implement the new .NET maui application, and test it from windows desktop, on a machine that has a BLE adapter. Once working, I'll setup a mac for iOS deployment.

UUIDs, services, and characteristics.

The main service UUID for the device, included in advertisement.
#define DELSOL_VEHICLE_SERVICE_UUID "8fb88487-73cf-4cce-b495-505a4b54b802"

Read/write/notify characteristic for general device status, w/ descriptor BLE2902.
provides an array of 5 bools, encoded in a string like so: "0,0,0,1,1"
these represent 5 booleans:
rear window down, trunk open, convertible roof down, car ignition on, headlights on.
#define DELSOL_STATUS_CHARACTERISTIC_UUID "40d527f5-3204-44a2-a4ee-d8d3c16f970e"

This characteristic publishes the car's battery voltage, as a 4 byte float.
#define DELSOL_BATTERY_CHARACTERISTIC_UUID "5c258bb8-91fc-43bb-8944-b83d0edc9b43"

// this is the service for updating the device firmware.
#define FIRMWARE_UPDATE_SERVICE_UUID "69da0f2b-43a4-4c2a-b01d-0f11564c732b"

notify/write_NR characteristic.
the app needs to write firmware here up to 512 bytes at a time during a FW update.
it will set and notify the value "success", "continue", or "error" after each buffer is received by the device.
#define FIRMWARE_UPDATE_WRITE_CHARACTERISTIC_UUID "7efc013a-37b7-44da-8e1c-06e28256d83b"

read only descriptor. publishes a fixed string, the version number of the currently installed FW.
#define FIRMWARE_UPDATE_VERSION_CHARACTERISTIC_UUID "a5c0d67a-9576-47ea-85c6-0347f8473cf3"

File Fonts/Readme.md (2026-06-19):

# Font Conversion Tool

The Adafruit GFX Library uses its own font format, and provides a tool for converting fonts to this format. This directory automates converting the TTF/OTF fonts in `input/` into Adafruit GFX headers in `output/`.

`go.sh` installs dependencies and runs `convert_fonts.py`, which (beyond the raw
headers) also generates a `Fonts::` namespace with an `enum class Font` and a
`GetFont(Font, int size)` lookup — see `instructions.md` for that design.

## Prerequisites

- Ubuntu or WSL Ubuntu
- Internet connection (for cloning dependencies)
- sudo access (for installing packages)
- Python 3 with venv module (`sudo apt install python3 python3-venv`)

## Usage

```bash
./go.sh
```

This converts every font in `input/` and writes the headers to `output/`
(both paths are fixed). To add a font, drop a `.ttf` or `.otf` into `input/`
and re-run `./go.sh`.

> Note: `input/` (source fonts) is committed; `output/` and `_deps/` are
> generated and gitignored. The firmware keeps its own copy of the fonts it
> actually uses in `firmware/include/fonts/`.

## What it does

1. **Environment Setup**: Verifies you're running on Ubuntu/WSL
2. **Dependency Management**: 
   - Installs `libfreetype6-dev` and `pkg-config` if needed
   - Creates a Python virtual environment in `_deps/python_venv/` (if not already present)
   - Installs `otf2ttf` package in the virtual environment (for OTF support)
   - Clones Adafruit GFX Library to `_deps/` folder (if not already present)
   - Builds the `fontconvert` tool (if not already built)
3. **Font Processing**: 
   - Converts any `.otf` files to temporary `.ttf` files using `otf2ttf`
   - Processes all `.ttf` files (original and converted) in the input directory
   - Generates headers for font sizes: 7, 8, 9, 10, 12, 14, 16 points
   - Output files named as: `<FontName><Size>pt7b.h`
   - Cleans up temporary converted files
4. **Master Files**: Creates `all_fonts.h` (font includes, `enum class Font`,
   and the `GetFont` declaration) and `all_fonts.cpp` (the `GetFont`
   implementation), both in the `Fonts::` namespace

## Output Structure

For a font file `MyFont.ttf` or `MyFont.otf`, the script generates:
```
output/
├── MyFont7pt7b.h
├── MyFont8pt7b.h
├── MyFont9pt7b.h
├── MyFont10pt7b.h
├── MyFont12pt7b.h
├── MyFont14pt7b.h
├── MyFont16pt7b.h
├── all_fonts.h
└── all_fonts.cpp
```

## Performance

The script caches dependencies in the `_deps/` folder to make subsequent runs faster. This includes:
- Built `fontconvert` tool
- Python virtual environment with `otf2ttf` installed
- Cloned Adafruit GFX Library

All cached files are preserved between runs for optimal performance.

## Troubleshooting

- **Permission errors**: Make sure you have sudo access for installing packages
- **Font conversion failures**: Check that your TTF/OTF files are valid and not corrupted
- **Build failures**: Ensure you have a working C compiler (usually installed with `build-essential`)
- **OTF conversion issues**: If OTF conversion fails, the script will warn but continue processing other fonts
- **Python errors**: Ensure Python 3 and python3-venv are installed (`sudo apt install python3 python3-venv`)
- **Virtual environment issues**: Delete `_deps/python_venv/` folder to force recreation on next run

## Integration

Include the generated header (and compile `all_fonts.cpp`) in your Arduino/C++
project:

```cpp
#include "all_fonts.h"

// Look up a font by enum + size:
display.setFont(Fonts::GetFont(Fonts::Font::JetBrainsMono, 12));

// Or reference a specific generated font directly:
display.setFont(&MyFont12pt7b);
```

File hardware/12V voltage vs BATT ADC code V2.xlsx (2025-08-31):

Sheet: Sheet1
Input | Measured Code | Linear Voltage | Linear Error | 2 poly Voltage | 2 Poly Error | 3 poly voltage | 3 poly error | 4 Poly Voltage | 4 poly error
1 | 156 | 0.1225 | 0.8775 | 1.499936 | 0.499936 | 0.8563716774 | 0.1436283226 | 1.029200051 | 0.02920005077
1 | 156 | 0.1225 | 0.8775 | 1.499936 | 0.499936 | 0.8563716774 | 0.1436283226 | 1.029200051 | 0.02920005077
1 | 154 | 0.1129 | 0.8871 | 1.497316 | 0.497316 | 0.845876336 | 0.154123664 | 1.023130767 | 0.02313076653
1 | 157 | 0.1273 | 0.8727 | 1.501249 | 0.501249 | 0.8616118752 | 0.1383881248 | 1.032239761 | 0.03223976056
1 | 152 | 0.1033 | 0.8967 | 1.494704 | 0.494704 | 0.8353610291 | 0.1646389709 | 1.01707506 | 0.01707506033
1 | 157 | 0.1273 | 0.8727 | 1.501249 | 0.501249 | 0.8616118752 | 0.1383881248 | 1.032239761 | 0.03223976056
1 | 153 | 0.1081 | 0.8919 | 1.496009 | 0.496009 | 0.8406211811 | 0.1593788189 | 1.020101211 | 0.02010121135
1 | 153 | 0.1081 | 0.8919 | 1.496009 | 0.496009 | 0.8406211811 | 0.1593788189 | 1.020101211 | 0.02010121135
1 | 151 | 0.0985 | 0.9015 | 1.493401 | 0.493401 | 0.8300958744 | 0.1699041256 | 1.014052323 | 0.01405232316
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

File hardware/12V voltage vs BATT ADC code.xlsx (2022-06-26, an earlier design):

Battery
Voltage | Code
4.7 | 1213.689655
5.52 | 1444.516129
6.33 | 1645.318182
8.31 | 2048.464286
9.89 | 2275.592593
12.02 | 2488.692308
12.55 | 2533.769231
12.9 | 2559.173913
13.41 | 2600.333333
14.06 | 2640
 |  | 3.567429809e-06 | -0.007518604453 | 8.781351365
 |  | 3.99086145e-07 | 0.001577221223 | 1.463232133
 |  | 0.9972644804 | 0.2088278334 | #N/A
 |  | 1275.964402 | 7 | #N/A
 |  | 111.2872266 | 0.3052634481 | #N/A

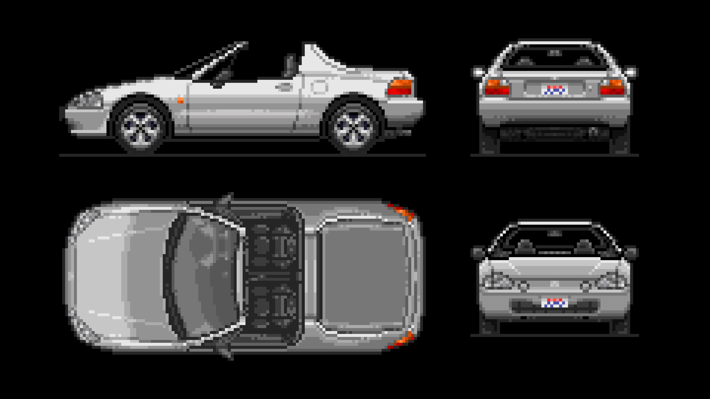
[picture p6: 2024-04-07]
Design/Design2/DS_PCA01.jpg

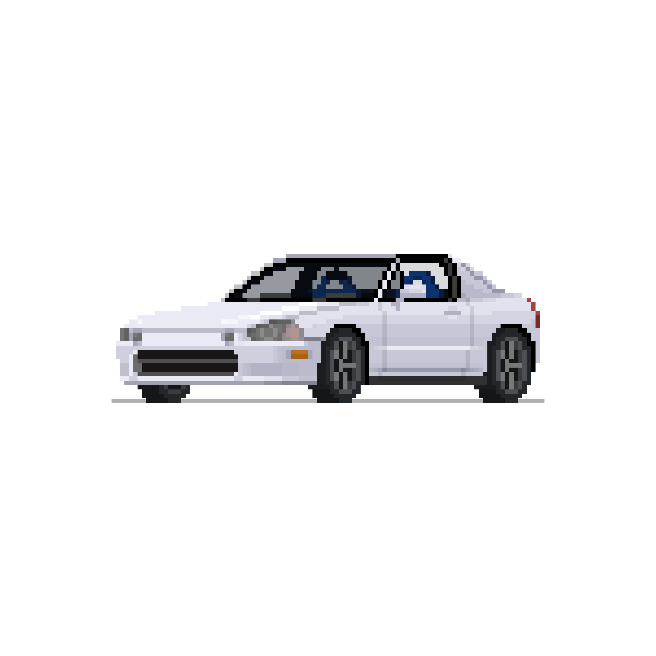
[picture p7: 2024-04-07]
Design/Design1/Honda Civic del Sol (3000x3000 pixel).png

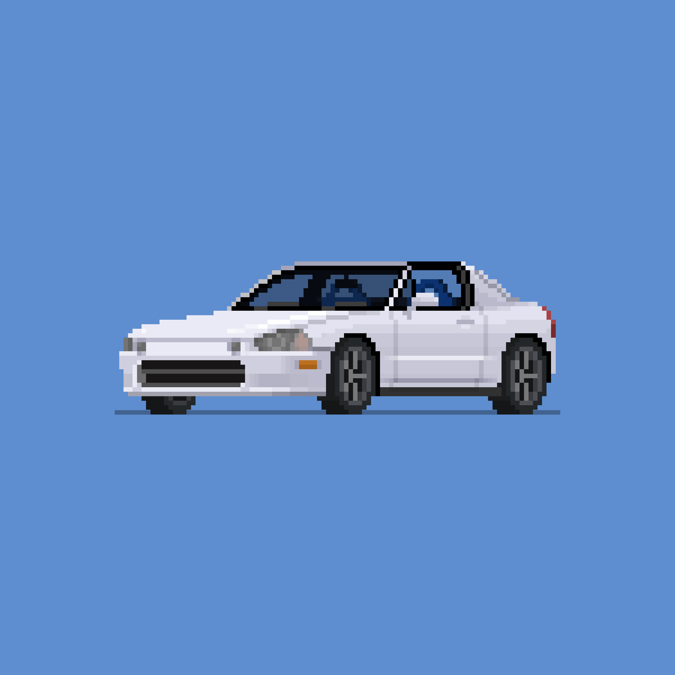
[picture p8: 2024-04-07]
Design/Design1/Honda Civic del Sol (3000x3000 pixel).jpg

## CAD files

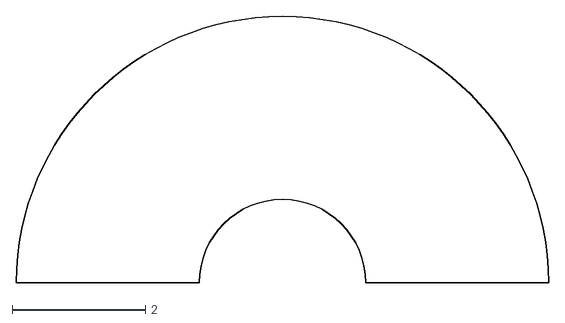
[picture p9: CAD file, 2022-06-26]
hardware/DelSol-bottomkeepout-bottomcenter.dxf
8.00 x 4.00

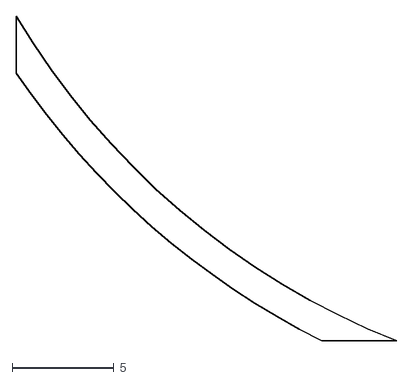
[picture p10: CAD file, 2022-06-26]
hardware/DelSol-bottomkeepout-bottom-left.dxf
18.7 x 16.0

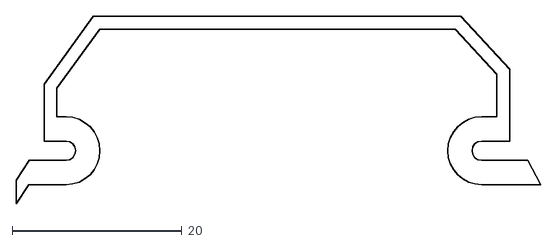
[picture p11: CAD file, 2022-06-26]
hardware/DelSol-bottomkeepout-top.dxf
61.8 x 22.1

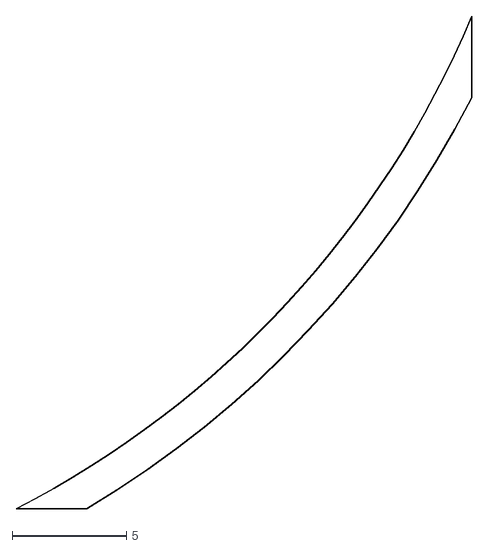
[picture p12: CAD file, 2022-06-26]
hardware/DelSol-bottomkeepout-bottomright.dxf
19.9 x 21.6

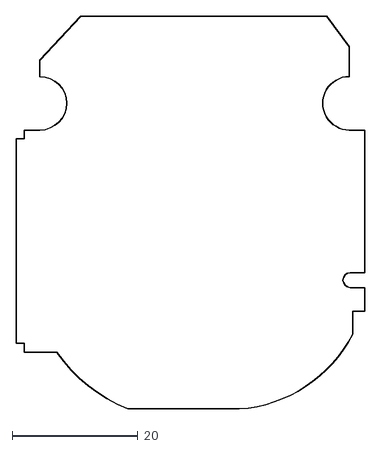
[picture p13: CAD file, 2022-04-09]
hardware/DelSolClockRearPCBOutline.dxf
55.4 x 62.4

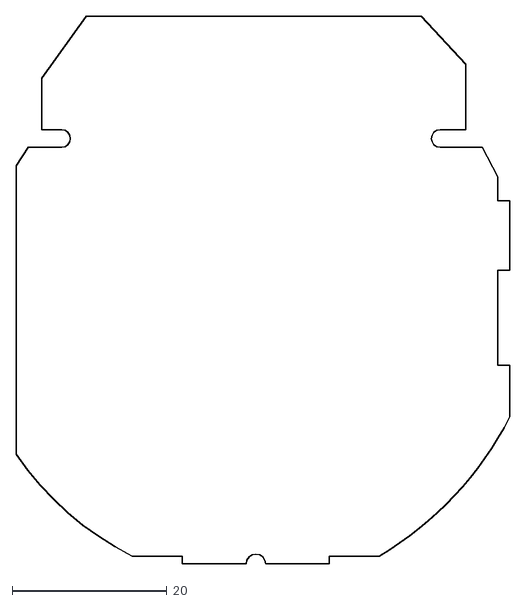
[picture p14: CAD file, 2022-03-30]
hardware/DelSolClockFrontPCBOutline.dxf
63.9 x 70.9

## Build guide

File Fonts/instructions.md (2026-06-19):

We need to make a number of changes to the output of the font convert script.

We should remove the forward declaration from the top of all_fonts.h

Instead, it should include correct header: #include <Adafruit_GFX.h>

I would like to generate a new enum class in all_fonts.g with the name "Font" and one entry per font. (not one per-size, just 1 per font)
I would like to auto-generate a a function with the signature: const GFXfont\* GetFont( Font font, int size )

GetFont should be implemented in a new file, all_fonts.cpp.
The body of GetFont should look like below, with 2 nested switch statements. The outer switch will be based on the font enum, and the inner switch will be based on the font size.

I would also like to rename the global "all_fonts" to "AllFonts" and leave a declaration in the header, but move the definition to the the new all_fonts.cpp file.

The goal is to allow consumers to include all_fonts.h, and then call GetFont, or iterate through the master list of fonts.

````
const GFXfont* GetFont( Font font, int size )
{
    switch( font )
    {
    case Font::AgaveNerd:
    {
        switch( size )
        {
        case 7:
            return &AgaveNerdFont_Regular7pt7b;
        case 8:
            return &AgaveNerdFont_Regular8pt7b;
        case 9:
            return &AgaveNerdFont_Regular9pt7b;
        case 10:
            return &AgaveNerdFont_Regular10pt7b;
        case 12:
            return &AgaveNerdFont_Regular12pt7b;
        case 14:
            return &AgaveNerdFont_Regular14pt7b;
        case 16:
            return &AgaveNerdFont_Regular16pt7b;
        default:
            return nullptr;
        }
    }
    break;
    case Font::AudioLink:
    {
        switch( size )
        {
        case 7:
            return &AudioLinkMono_Regular7pt7b;
        case 8:
            return &AudioLinkMono_Regular8pt7b;
        case 9:
            return &AudioLinkMono_Regular9pt7b;
        case 10:
            return &AudioLinkMono_Regular10pt7b;
        case 12:
            return &AudioLinkMono_Regular12pt7b;
        case 14:
            return &AudioLinkMono_Regular14pt7b;
        case 16:
            return &AudioLinkMono_Regular16pt7b;
        default:
            return nullptr;
        }
    }
    break;
    // ...
    ```
````

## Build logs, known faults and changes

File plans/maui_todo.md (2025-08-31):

# MAUI App Development TODO

## Current State Analysis
The .NET MAUI app has basic structure with 3 tabs (Status, Firmware, Logs) but most functionality is stubbed out:
- **DelSolConnection**: Has UUIDs defined but no actual BLE implementation
- **StatusPage**: Shows hardcoded "Connected" status and dummy data
- **UpdatePage**: Can fetch GitHub releases but firmware update is stubbed
- **LogPage**: Shows dummy logs
- **Dependencies**: Plugin.BLE and RestSharp already included

## Phase 1: Foundation & BLE Core Implementation

### 1.1 BLE Service Implementation
- **Priority**: HIGH
- **Effort**: 3-4 days
- Replace DelSolConnection stub with actual Plugin.BLE implementation
- Implement device discovery filtering by service UUID `8fb88487-73cf-4cce-b495-505a4b54b802`
- Add connection/disconnection logic with proper error handling
- Implement connection state management and events

### 1.2 Characteristic Reading Infrastructure
- **Priority**: HIGH  
- **Effort**: 2-3 days
- Implement reading from status characteristic `40d527f5-3204-44a2-a4ee-d8d3c16f970e`
- Implement reading from battery characteristic `5c258bb8-91fc-43bb-8944-b83d0edc9b43`
- Implement reading from firmware version characteristic `a5c0d67a-9576-47ea-85c6-0347f8473cf3`
- Add notification handling for status updates
- Parse status string format "0,0,0,1,1" into meaningful data

### 1.3 Connection Management UI
- **Priority**: HIGH
- **Effort**: 2 days
- Add device discovery/pairing screen or functionality
- Update StatusPage to show actual connection status
- Add reconnection logic and error handling
- Implement proper disposal patterns for BLE resources

## Phase 2: Status Screen Implementation

### 2.1 Status Data Display
- **Priority**: HIGH
- **Effort**: 2-3 days
- Replace dummy data in StatusPage with actual BLE readings
- Implement real-time updates from device notifications
- Display battery voltage (from float characteristic)
- Display all 5 boolean status indicators:
  - Rear Window (up/down)
  - Trunk (open/closed) 
  - Convertible roof (up/down)
  - Car ignition (on/off)
  - Headlights (on/off)

### 2.2 Status UI Improvements
- **Priority**: MEDIUM
- **Effort**: 1-2 days
- Improve status display with icons (already have some in Resources/Images/icons/)
- Add visual indicators for each status item
- Implement proper error states for disconnected device
- Add refresh functionality

## Phase 3: Firmware Update Implementation

### 3.1 Firmware Update Core Logic
- **Priority**: HIGH
- **Effort**: 4-5 days
- Implement firmware download from GitHub release assets
- Implement 512-byte chunked BLE writing to characteristic `7efc013a-37b7-44da-8e1c-06e28256d83b`
- Handle response parsing ("success", "continue", "error")
- Implement proper timeout and error handling
- Handle edge case: send zero-length value if firmware is exact multiple of 512 bytes

### 3.2 Firmware Update UI
- **Priority**: MEDIUM
- **Effort**: 2-3 days
- Add progress bar for firmware updates
- Implement cancel functionality
- Show current firmware version at top of UpdatePage
- Mark installed firmware versions in release list
- Add proper error dialogs and user feedback

### 3.3 GitHub Release Integration
- **Priority**: LOW (mostly done)
- **Effort**: 1 day
- FirmwareBrowser is mostly complete, minor refinements only
- Ensure proper asset filtering (.bin files)
- Add error handling for network issues

## Phase 4: Logs Implementation

### 4.1 Log Reading Infrastructure
- **Priority**: MEDIUM
- **Effort**: 3-4 days
- **Note**: Requires firmware changes - this phase may be delayed
- Research and implement log reading mechanism (circular buffer or notification characteristic)
- Parse log format: `[timestamp] [level] [file:line] message`
- Implement real-time log streaming if using notifications

### 4.2 Log Display and Management  
- **Priority**: MEDIUM
- **Effort**: 2 days
- Replace dummy logs with actual device logs
- Implement scrollable log display with proper formatting
- Add log saving functionality with date/time stamped filenames
- Implement log clearing functionality

## Phase 5: Polish & Platform-Specific Features

### 5.1 Cross-Platform Testing
- **Priority**: HIGH
- **Effort**: 3-4 days
- Test on Windows desktop with BLE adapter
- Verify BLE permissions on Android/iOS
- Test UI responsiveness across screen sizes
- Handle platform-specific BLE quirks

### 5.2 Error Handling & UX
- **Priority**: MEDIUM  
- **Effort**: 2 days
- Improve error messages and user guidance
- Add loading states and spinners
- Implement proper navigation patterns
- Add app settings/preferences if needed

### 5.3 Final Polish
- **Priority**: LOW
- **Effort**: 1-2 days
- Update app icons and branding
- Improve color scheme and styling
- Add about screen if needed
- Performance optimization

## Development Order Recommendations

**Sprint 1 (Week 1-2)**: Phase 1 (BLE Foundation)
- Critical foundation for all other features
- Must be solid before building other functionality

**Sprint 2 (Week 3)**: Phase 2 (Status Screen)  
- Builds directly on BLE foundation
- Provides immediate user value

**Sprint 3 (Week 4-5)**: Phase 3 (Firmware Updates)
- Most complex feature requiring careful implementation
- High user value once working

**Sprint 4 (Week 6)**: Phase 4 (Logs) - Optional/Future
- May require firmware changes
- Lower priority than other features

**Sprint 5 (Week 7)**: Phase 5 (Polish)
- Final testing and refinement
- Platform-specific adjustments

## Technical Notes

### Key Dependencies
- Plugin.BLE 3.2.0-beta.1 (already added)
- RestSharp 112.1.0 (already added)
- .NET MAUI targeting net9.0

### BLE Service/Characteristic UUIDs (from plan)
```
Main Service: 8fb88487-73cf-4cce-b495-505a4b54b802
Status Characteristic: 40d527f5-3204-44a2-a4ee-d8d3c16f970e  
Battery Characteristic: 5c258bb8-91fc-43bb-8944-b83d0edc9b43
Firmware Service: 69da0f2b-43a4-4c2a-b01d-0f11564c732b
Firmware Write: 7efc013a-37b7-44da-8e1c-06e28256d83b
Firmware Version: a5c0d67a-9576-47ea-85c6-0347f8473cf3
```

### Risk Areas
- BLE reliability across platforms (especially Windows)
- Firmware update protocol complexity and error handling
- Log streaming implementation (may need firmware changes)
- Cross-platform permission handling

## Estimated Total Timeline
**6-7 weeks** for full implementation, with core functionality (Phases 1-3) available in 4-5 weeks.

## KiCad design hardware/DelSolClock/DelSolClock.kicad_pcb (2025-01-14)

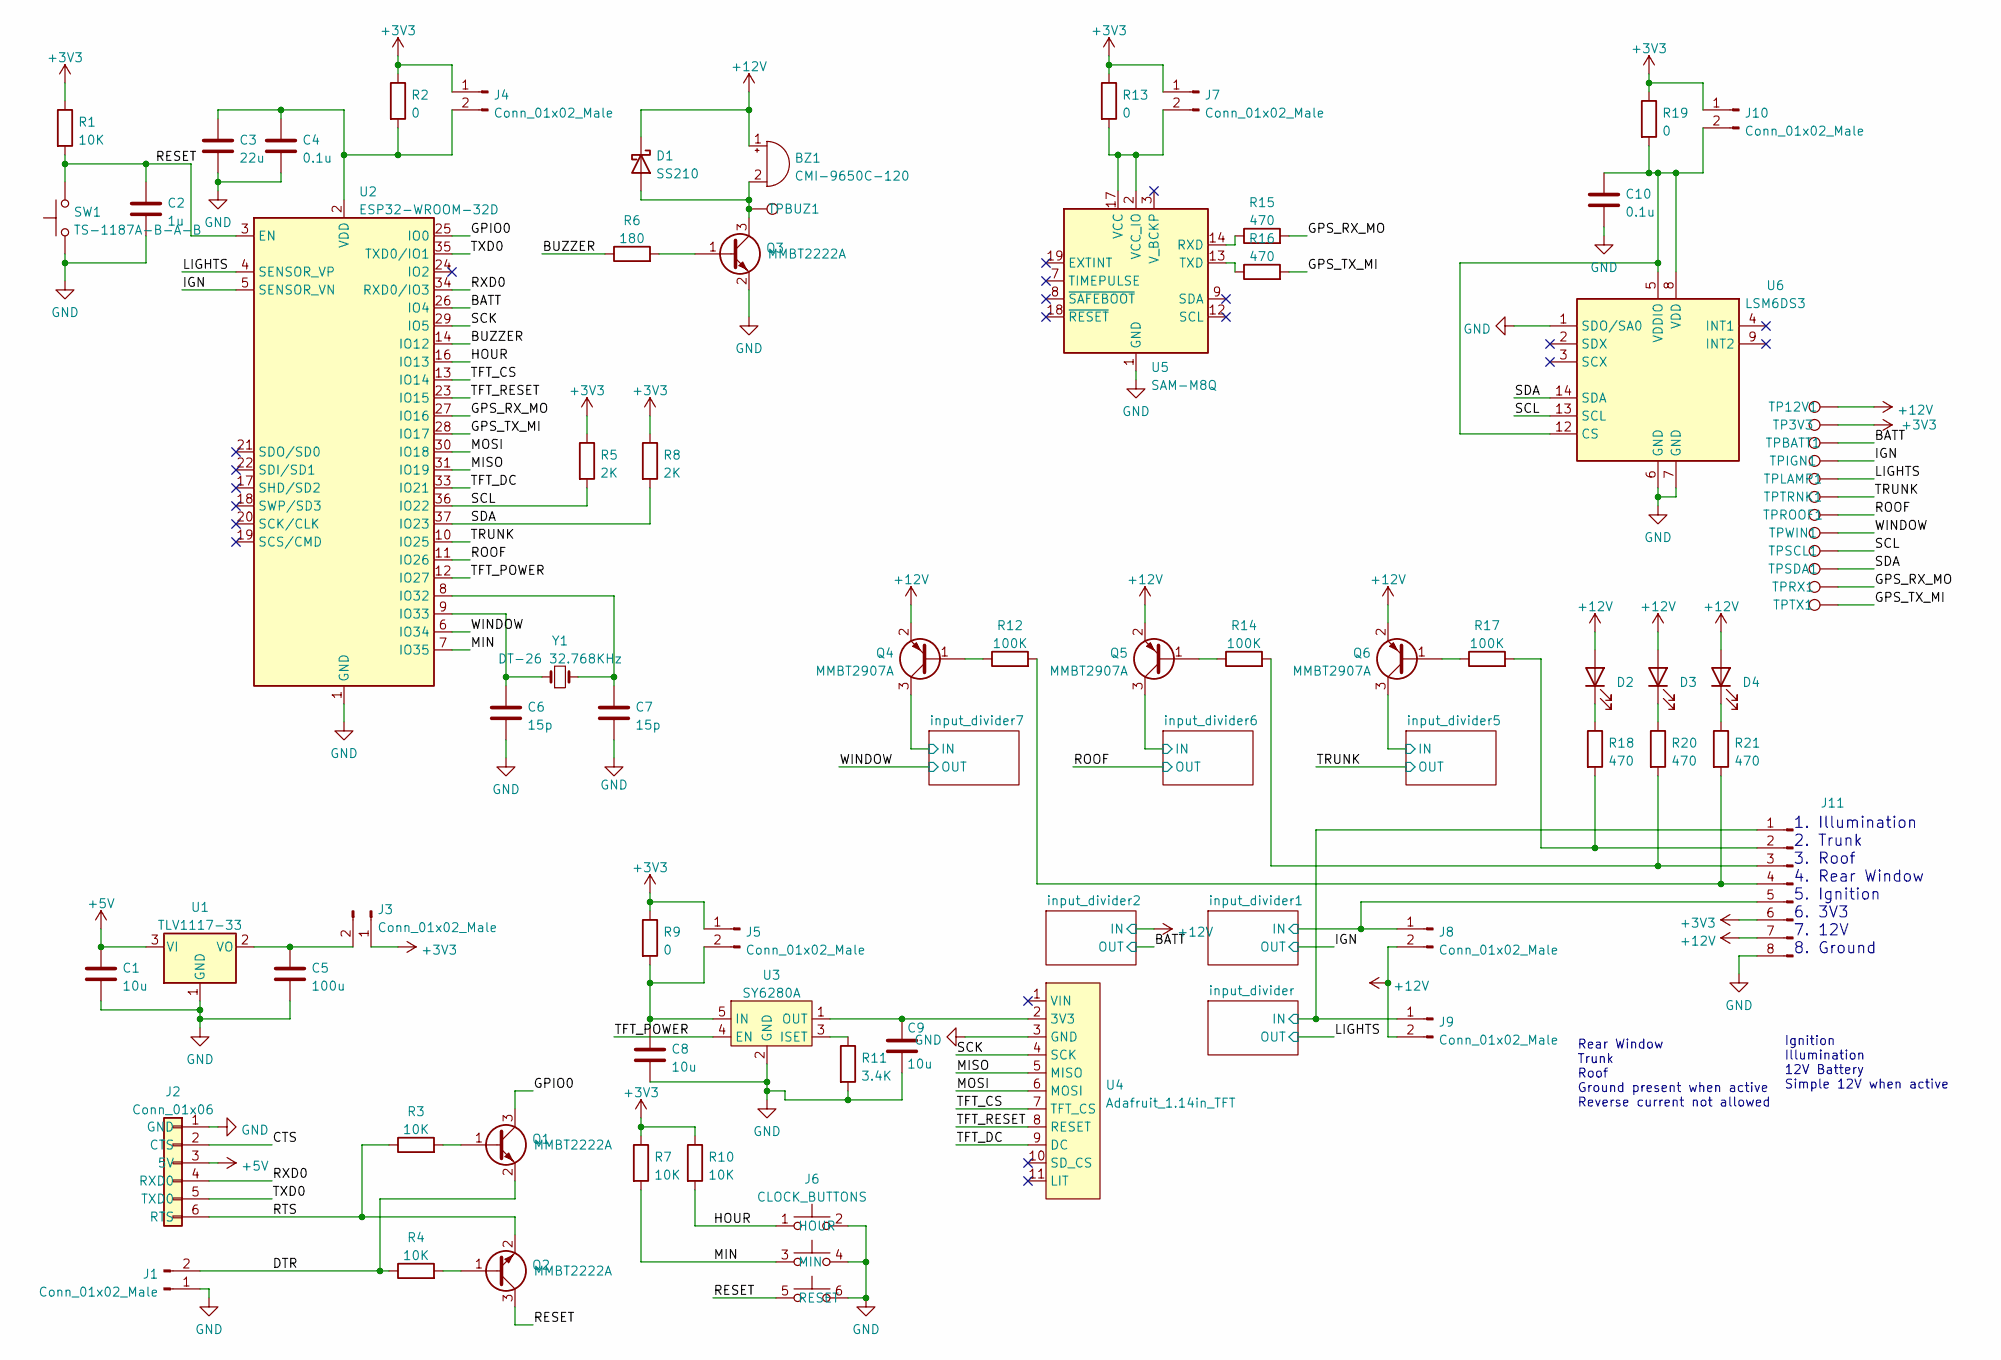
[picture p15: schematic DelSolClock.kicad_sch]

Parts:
BZ1: CMI-9650C-120; Buzzer_CUI-CMI-9650C-120
C1, C8, C9: 10u; C_0805_2012Metric_Pad1.18x1.45mm_HandSolder
C2: 1u; C_0805_2012Metric_Pad1.18x1.45mm_HandSolder
C3: 22u; C_0805_2012Metric_Pad1.18x1.45mm_HandSolder
C4, C10: 0.1u; C_0805_2012Metric_Pad1.18x1.45mm_HandSolder
C5: 100u; C_1206_3216Metric_Pad1.33x1.80mm_HandSolder
C6, C7: 15p; C_0805_2012Metric_Pad1.18x1.45mm_HandSolder
D1: SS210; D_SMA_Handsoldering
D2, D3: SSL-LX4673ID-LA20; LED_Rectangular_W3.65mm_L6.15mm
D4: WP132XGD; LED_D3.0mm
J1, J3, J4, J5, J7, J8, J9, J10: Conn_01x02_Male; PinHeader_1x02_P2.54mm_Vertical
J2: Conn_01x06; PinHeader_1x06_P2.54mm_Vertical
J6: CLOCK_BUTTONS; Switch_DelSol
J11: Conn_01x08_Male; PinHeader_1x08_P2.54mm_Vertical
Q1, Q2, Q3: MMBT2222A; SOT-23
Q4, Q5, Q6: MMBT2907A; SOT-23
R1, R3, R4, R7, R10: 10K; R_0805_2012Metric_Pad1.20x1.40mm_HandSolder
R2, R9, R13, R19: 0; R_0805_2012Metric_Pad1.20x1.40mm_HandSolder
R5, R8: 2K; R_0805_2012Metric_Pad1.20x1.40mm_HandSolder
R6: 180; R_0805_2012Metric_Pad1.20x1.40mm_HandSolder
R11: 3.4K; R_0805_2012Metric_Pad1.20x1.40mm_HandSolder
R12, R14, R17: 100K; R_0805_2012Metric_Pad1.20x1.40mm_HandSolder
R15, R16, R18, R20, R21: 470; R_0805_2012Metric_Pad1.20x1.40mm_HandSolder
SW1: TS-1187A-B-A-B; SW_SPST_SKQG_WithoutStem
TP3V3, TP12V1: TestPoint; TestPoint_Keystone_5000-5004_Miniature
TPBATT1: TestPoint; TestPoint_Keystone_5000-5004_Miniature
TPBUZ1: TestPoint; TestPoint_Keystone_5000-5004_Miniature
TPIGN1: TestPoint; TestPoint_Keystone_5000-5004_Miniature
TPLAMP1: TestPoint; TestPoint_Keystone_5000-5004_Miniature
TPROOF1: TestPoint; TestPoint_Keystone_5000-5004_Miniature
TPRX1: TestPoint; TestPoint_Keystone_5000-5004_Miniature
TPSCL1: TestPoint; TestPoint_Keystone_5000-5004_Miniature
TPSDA1: TestPoint; TestPoint_Keystone_5000-5004_Miniature
TPTRNK1: TestPoint; TestPoint_Keystone_5000-5004_Miniature
TPTX1: TestPoint; TestPoint_Keystone_5000-5004_Miniature
TPWIN1: TestPoint; TestPoint_Keystone_5000-5004_Miniature
U1: TLV1117-33; SOT-223
U2: ESP32-WROOM-32D; ESP32-WROOM-32
U3: SY6280A; SOT-23-5
U4: Adafruit_1.14in_TFT
U5: SAM-M8Q; ublox_SAM-M8Q
U6: LSM6DS3; LGA-14_3x2.5mm_P0.5mm_LayoutBorder3x4y
Y1: DT-26 32.768KHz; Crystal_DS26_D2.0mm_L6.0mm_Horizontal_1EP_style1

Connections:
+3V3: J3.1, J4.1, J5.1, J7.1, J10.1, J11.6 (3V3), R1.1, R2.1, R5.1, R7.1, R8.1, R9.1, R10.1, R13.1, R19.1, TP3V3.1
+5V: C1.1, J2.3 (5V), U1.3 (VI)
+12V: BZ1.1 (-), D1.1 (K), D2.2 (A), D3.2 (A), D4.2 (A), J8.2, J9.2, J11.7 (12V), Q4.2 (E), Q5.2 (E), Q6.2 (E), TP12V1.1; also elsewhere on the board
/BATT: TPBATT1.1, U2.26 (IO4); also elsewhere on the board
/BUZZER: R6.1, U2.14 (IO12)
/CTS: J2.2 (CTS)
/DTR: J1.2, Q1.2 (E), R4.1
/GPIO0: Q1.3 (C), U2.25 (IO0)
/GPS_RX_MO: R15.2, TPRX1.1, U2.27 (IO16)
/GPS_TX_MI: R16.2, TPTX1.1, U2.28 (IO17)
/HOUR: J6.1 (HOUR), R10.2, U2.16 (IO13)
/IGN: TPIGN1.1, U2.5 (SENSOR_VN); also elsewhere on the board
/LIGHTS: TPLAMP1.1, U2.4 (SENSOR_VP); also elsewhere on the board
/MIN: J6.3 (MIN), R7.2, U2.7 (IO35)
/MISO: U2.31 (IO19), U4.5 (MISO)
/MOSI: U2.30 (IO18), U4.6 (MOSI)
/RESET: C2.1, J6.5 (RESET), Q2.3 (C), R1.2, SW1.2, U2.3 (EN)
/ROOF: TPROOF1.1, U2.11 (IO26); also elsewhere on the board
/RTS: J2.6 (RTS), Q2.2 (E), R3.1
/RXD0: J2.4 (RXD0), U2.34 (RXD0/IO3)
/SCK: U2.29 (IO5), U4.4 (SCK)
/SCL: R5.2, TPSCL1.1, U2.36 (IO22), U6.13 (SCL)
/SDA: R8.2, TPSDA1.1, U2.37 (IO23), U6.14 (SDA)
/TFT_CS: U2.13 (IO14), U4.7 (TFT_CS)
/TFT_DC: U2.33 (IO21), U4.9 (DC)
/TFT_POWER: U2.12 (IO27), U3.4 (EN)
/TFT_RESET: U2.23 (IO15), U4.8 (RESET)
/TRUNK: TPTRNK1.1, U2.10 (IO25); also elsewhere on the board
/TXD0: J2.5 (TXD0), U2.35 (TXD0/IO1)
/WINDOW: TPWIN1.1, U2.6 (IO34); also elsewhere on the board
/input_divider1/IN: J8.1, J11.5 (Ignition); also elsewhere on the board
/input_divider5/IN: Q6.3 (C); also elsewhere on the board
/input_divider6/IN: Q5.3 (C); also elsewhere on the board
/input_divider7/IN: Q4.3 (C); also elsewhere on the board
/input_divider/IN: J9.1, J11.1 (Illumination); also elsewhere on the board
GND: C1.2, C2.2, C3.2, C4.2, C5.2, C6.2, C7.2, C8.2, C9.2, C10.2, J1.1, J2.1 (GND), J6.2, J6.4, J6.6, J11.8 (GND), Q3.2 (E), R11.2, SW1.1, U1.1 (GND), U2.1 (GND), U2.15 (GND), U2.38 (GND), U2.39 (GND), U3.2 (GND), U4.3 (GND), U5.1 (GND), U5.4 (GND), U5.5 (GND), U5.6 (GND), U5.10 (GND), U5.11 (GND), U5.15 (GND), U5.16 (GND), U5.20 (GND), U6.1 (SDO/SA0), U6.6 (GND), U6.7 (GND); also elsewhere on the board
unnamed: BZ1.2 (+), D1.2 (A), Q3.3 (C), TPBUZ1.1
unnamed: D2.1 (K), R18.1
unnamed: D3.1 (K), R20.1
unnamed: D4.1 (K), R21.1
unnamed: C5.1, J3.2, U1.2 (VO)
unnamed: C3.1, C4.1, J4.2, R2.2, U2.2 (VDD)
unnamed: C8.1, J5.2, R9.2, U3.5 (IN)
unnamed: J7.2, R13.2, U5.2 (VCC_IO), U5.17 (VCC)
unnamed: C10.1, J10.2, R19.2, U6.5 (VDDIO), U6.8 (VDD), U6.12 (CS)
unnamed: J11.4 (Rear_Window), R12.2, R21.2
unnamed: J11.3 (Roof), R14.2, R20.2
unnamed: J11.2 (Trunk), R17.2, R18.2
unnamed: Q1.1 (B), R3.2
unnamed: Q2.1 (B), R4.2
unnamed: Q3.1 (B), R6.2
unnamed: Q4.1 (B), R12.1
unnamed: Q5.1 (B), R14.1
unnamed: Q6.1 (B), R17.1
unnamed: C7.1, U2.8 (IO32), Y1.2
unnamed: C6.1, U2.9 (IO33), Y1.1
unnamed: R11.1, U3.3 (ISET)
unnamed: C9.1, U3.1 (OUT), U4.2 (3V3)
unnamed: R15.1, U5.14 (RXD)
unnamed: R16.1, U5.13 (TXD)

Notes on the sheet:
Rear Window Trunk Roof Ground present when active Reverse current not allowed
1. Illumination 2. Trunk 3. Roof 4. Rear Window 5. Ignition 6. 3V3 7. 12V 8. Ground
Ignition Illumination 12V Battery Simple 12V when active

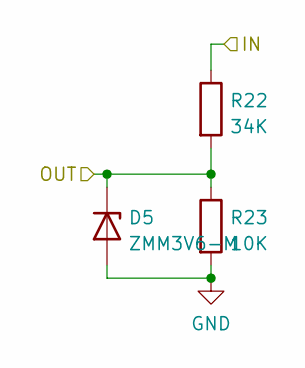
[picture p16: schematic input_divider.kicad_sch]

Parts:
D5: ZMM3V6-M; D_MiniMELF
R22: 34K; R_0805_2012Metric_Pad1.20x1.40mm_HandSolder
R23: 10K; R_0805_2012Metric_Pad1.20x1.40mm_HandSolder

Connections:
/LIGHTS: D5.1 (K), R22.2, R23.1; also elsewhere on the board
/input_divider/IN: R22.1; also elsewhere on the board
GND: D5.2 (A), R23.2; also elsewhere on the board

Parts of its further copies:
D6, D7, D8, D9, D10: ZMM3V6-M; D_MiniMELF
R24, R26, R28, R30, R32: 34K; R_0805_2012Metric_Pad1.20x1.40mm_HandSolder
R25, R27, R29, R31, R33: 10K; R_0805_2012Metric_Pad1.20x1.40mm_HandSolder

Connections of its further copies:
+12V: R26.1; also elsewhere on the board
/BATT: D7.1 (K), R26.2, R27.1; also elsewhere on the board
/IGN: D6.1 (K), R24.2, R25.1; also elsewhere on the board
/ROOF: D8.1 (K), R28.2, R29.1; also elsewhere on the board
/TRUNK: D10.1 (K), R32.2, R33.1; also elsewhere on the board
/WINDOW: D9.1 (K), R30.2, R31.1; also elsewhere on the board
/input_divider1/IN: R24.1; also elsewhere on the board
/input_divider5/IN: R32.1; also elsewhere on the board
/input_divider6/IN: R28.1; also elsewhere on the board
/input_divider7/IN: R30.1; also elsewhere on the board
GND: D6.2 (A), D7.2 (A), D8.2 (A), D9.2 (A), D10.2 (A), R25.2, R27.2, R29.2, R31.2, R33.2; also elsewhere on the board

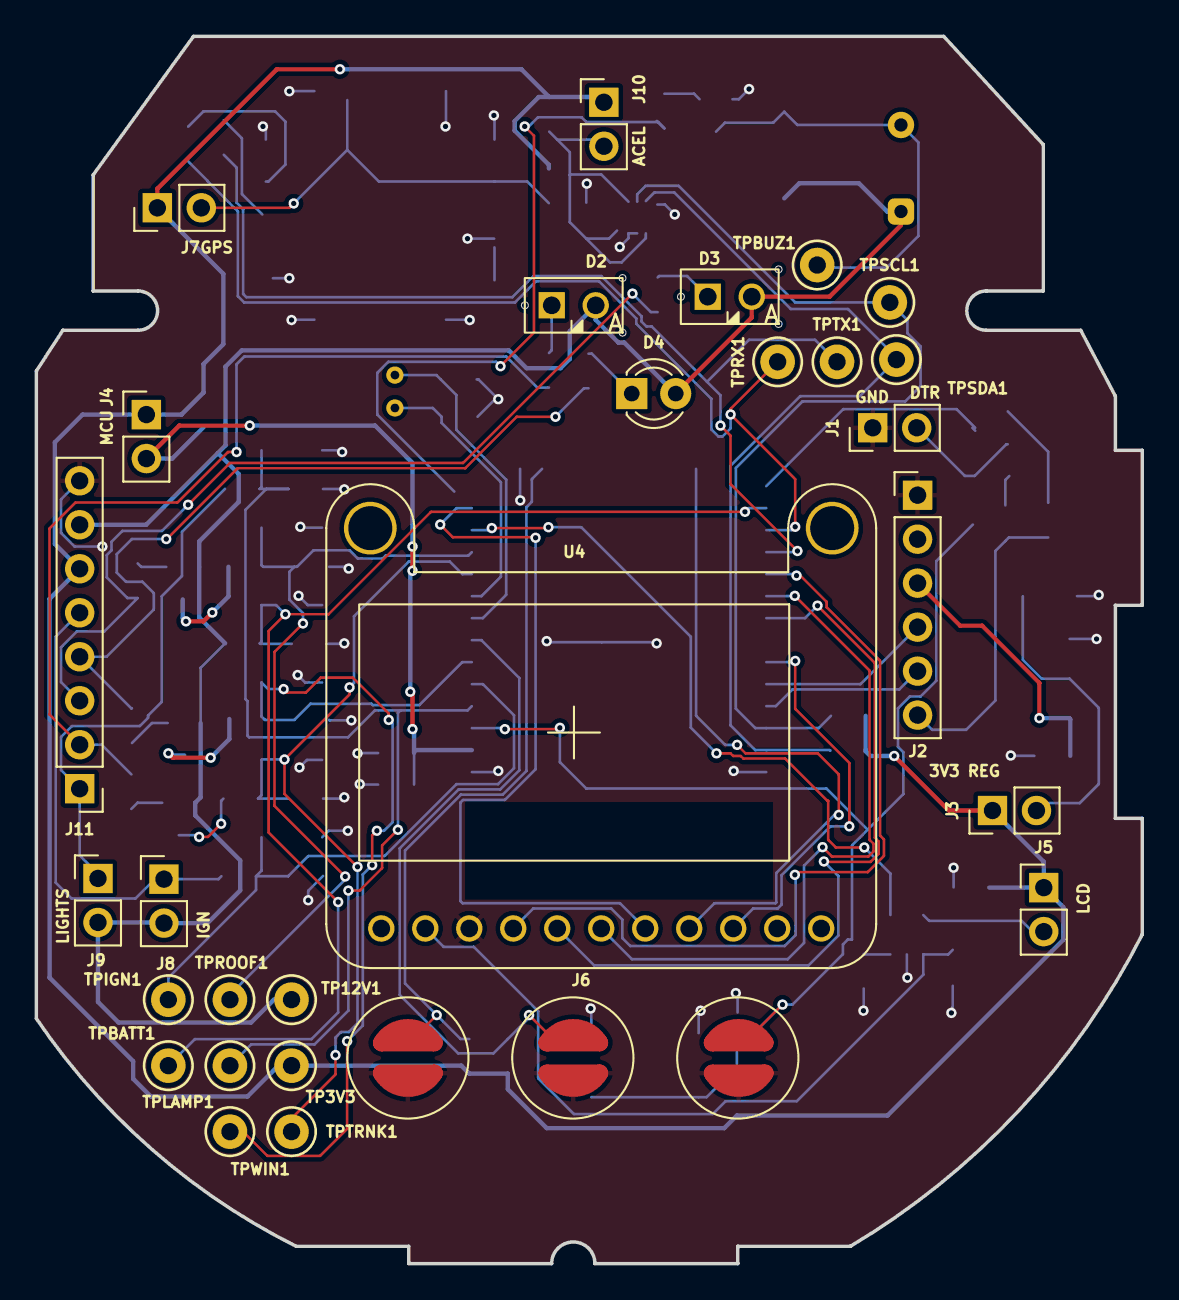
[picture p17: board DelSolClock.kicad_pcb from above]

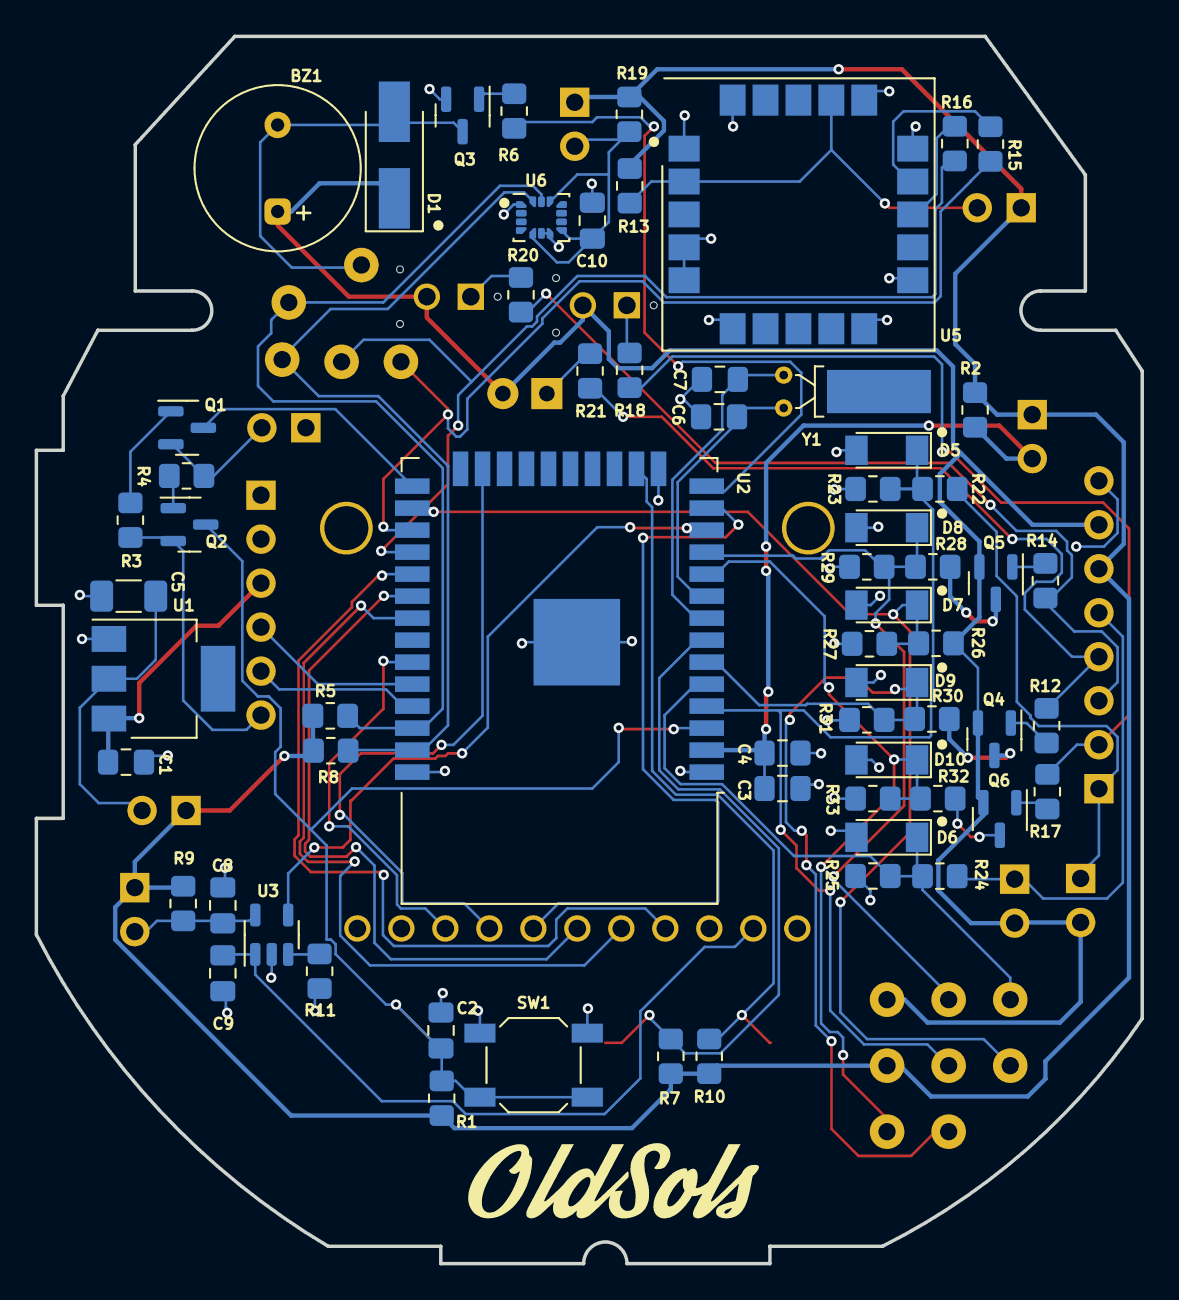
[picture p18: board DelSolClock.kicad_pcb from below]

Board: 2 copper layers, 63.8 x 70.9 mm, 92 parts (64 on the bottom side), 59 nets.

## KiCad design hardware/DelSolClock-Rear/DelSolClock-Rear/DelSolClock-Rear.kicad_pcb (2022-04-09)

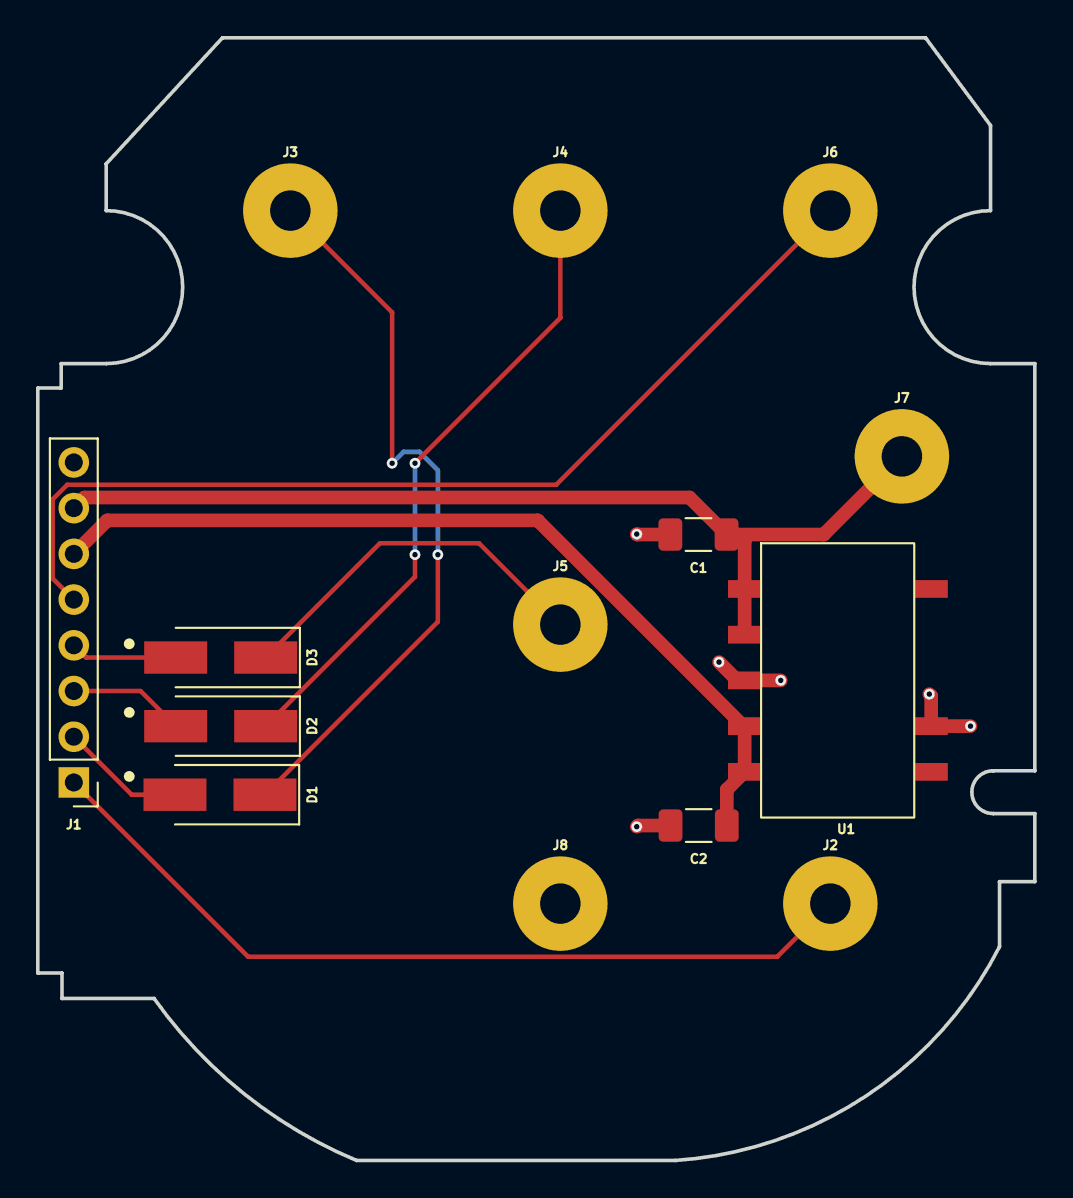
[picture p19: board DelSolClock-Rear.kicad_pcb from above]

Board: 2 copper layers, 55.4 x 62.4 mm, 14 parts (0 on the bottom side), 11 nets.

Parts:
C1: 10u; C_1206_3216Metric_Pad1.33x1.80mm_HandSolder
C2: 22u; C_1206_3216Metric_Pad1.33x1.80mm_HandSolder
D1, D2, D3: D_Schottky; D_SMA_Handsoldering
J1: Conn_01x08; PinHeader_1x08_P2.54mm_Vertical
J2, J3, J4, J5, J6, J7, J8: Terminal_Spring_Del_Sol
U1: K7803T-500R3

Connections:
+3V3: C2.1, J1.6, U1.4 (+Vout), U1.5 (+Vout)
+12V: C1.1, J1.7, J7.1, U1.1 (+Vin), U1.2 (+Vin)
/IGN: J1.5, J6.1
/ILL: J1.1, J2.1
/ROOF: D2.1 (K), J4.1
/TRUNK: D1.1 (K), J3.1
/WINDOW: D3.1 (K), J5.1
GND: C1.2, C2.2, J1.8, J8.1, U1.3 (GND), U1.7 (GND)
unnamed: D1.2 (A), J1.2
unnamed: D2.2 (A), J1.3
unnamed: D3.2 (A), J1.4

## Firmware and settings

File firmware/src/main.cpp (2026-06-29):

#include <Arduino.h>
#include "apple_media_service.h"
#if ENABLE_APPLE_NOTIFICATIONS
#include "apple_notification_center_service.h"
#include "notification_processor.h"
#endif
#include "current_time_service.h"
#include "apple_media_service.h"
#include "tft.h"
#include "display_config.h"
#include "draw_helpers.h"
#include "clock_screen.h"
#include "simple_screens.h"
#include "status_screen.h"
#include "notification_screens.h"
#include "perspective_screen.h"
#include "nav_overlay.h"
#include "centerline.h"
#include "gmeter_screen.h"
#include "image_loader.h"
#include "pins.h"
#include "car_io.h"
#include "bluetooth.h"
#include "gps.h"
#include "gps_recorder.h"
#include "ble_ota.h"
#include "motion.h"
#include "demo.h"
#include "quarter_mile.h"
#include "navigation_service.h"
#include "matcher.h"
#include "sun.h"
#include "logger.h"
#include "debug_service.h"
#include "utilities.h"

#include <TinyGPSPlus.h>

#include <time.h>
#include <sys/time.h>

#include <esp_task_wdt.h>

#include "soc/rtc.h"


enum class CurrentScreen
{
    Default, // clock, OTA, splash, etc.
    Status,
    QM,
    Notifications,
    Navigation,
    GMeter,
};


// define this when targeting a Adafruit Feather board, instead of a Del Sol Clock. Useful for testing BLE.
// #define DISABLE_SLEEP
// define this to run the demo mode, which will cycle through all the screens.
// #define DEMO_MODE
namespace
{
    bool FwUpdateInProgress = false;
    uint32_t FwBytesReceived = 0;
    bool LightsAlarmActive = false;
    const std::string BluetoothDeviceName = "Del Sol";

    Tft::Tft* gTft;
    GFXcanvas16 gDisplay( display::kWidth, display::kHeight );
    CurrentScreen gCurrentScreen = CurrentScreen::Default;

    // Latest navigation match result, updated by the live matcher when a route is
    // loaded + GPS is fresh. Consumed by the Navigation screen render.
    nav::MatchResult gNavResult;
    bool gNavHasFix = false;        // GPS had a fresh fix at last match
    std::string gNavInstruction;    // next-maneuver instruction (owns the string)
    std::vector<nav::LocalPoint> gNavCenterline;  // upcoming route, car-local meters

    Motion::HistoryTracker BrakeHistoryTracker( display::GMeterProps::HistorySize, 100 );
    Motion::HistoryTracker LateralHistoryTracker( display::GMeterProps::HistorySize, 100 );
}

void HandlePowerState( const CarIO::CarStatus& car_status );
void Sleep();


void setup()
{
    Serial.begin( 115200 );
    LOG_TRACE( "Del Sol Clock Booting" );

    Serial.println( "Configuring WDT..." );
    esp_task_wdt_init( 50, true ); // huge because I have not done a great job of resetting the watchdog timer.
    esp_task_wdt_add( NULL );

    PRINT_MEMORY_USAGE();

    // show the current clock source. If it's not 1 (the external 32kHz crystal), then either (A) the crystal is not present, or (B) the
    // bootloader & esp32-arduino library was not configured for it.
    auto src = rtc_clk_slow_freq_get();
    auto hz = rtc_clk_slow_freq_get_hz();
    LOG_TRACE( "RTC_SLOW_CLK frequency: %u Hz, source: %i", hz, src );

    // Required before we can handle the lights-only power mode.
    CarIO::Setup();
    DisplayConfig::Begin();  // load persisted bezel offsets before any draw
    gTft = new Tft::Tft();
    gTft->Init();

    // Measure the cost of hashing the whole SPIFFS partition at boot. This is the
    // identity we expose so the web app can tell which release's filesystem image
    // is currently loaded. Logging the time confirms it's cheap enough to do on boot.
    {
        uint32_t hash_ms = 0;
        std::string spiffs_hash = BleOta::HashSpiffsPartition( &hash_ms );
        LOG_INFO( "SPIFFS partition sha256: %s (computed in %u ms)", spiffs_hash.c_str(), hash_ms );
    }

    Gps::Begin();
    GpsRecorder::Begin();
    Motion::Begin();
    {
        const char* images_to_preload[] = { "/bluetooth.bmp", "/light_small.bmp", "/light_large.bmp", "/left.bmp", "/right.bmp" };
        for( const char* image : images_to_preload )
        {
            display::PreloadImage( image );
        }
    }
#if ENABLE_APPLE_NOTIFICATIONS
    NotificationProcessor::Init();
#endif

    {
        // write the splash screen to the display buffer before starting BLE. this uses a huge amount of RAM temporarily.
        display::DrawSplash( &gDisplay );
        gTft->DrawCanvas( &gDisplay );
        // gTft->DrawBMPDDirect( "/OldSols.bmp" );
    }

    Bluetooth::Begin( BluetoothDeviceName );
    // leave splash screen up for a few seconds.
    delay( 3000 );


#ifdef DEMO_MODE
    while( 1 )
    {
        Demo::Demo( &gDisplay, gTft );
        esp_task_wdt_reset();
    }
#endif

    // go back to sleep if the car is off, or go into the alarm mode if the lights are on.
    LOG_TRACE( "setup, HandlePowerState..." );
    HandlePowerState( CarIO::GetStatus() );

    // if the ignition is off, we wait until it's on, or we go to sleep.
    while( LightsAlarmActive )
    {
        HandlePowerState( CarIO::GetStatus() );
        CarIO::Service();
        esp_task_wdt_reset();
    }
    LOG_TRACE( "setup, GPS wake..." );
    Gps::Wake();

    LOG_TRACE( "setup, bluetooth service..." );
    Bluetooth::Service(); // service once to see if we're already connected!
    if( !Bluetooth::IsConnected() )
    {
        // if we're still not connected, display the connection message. If we still have correct time stored in the RTC system, show time
        // too.
        display::DiscoverableProps discoverable;
        discoverable.bluetoothName = BluetoothDeviceName.c_str();
        display::DrawDiscoverable( &gDisplay, discoverable );
        gTft->DrawCanvas( &gDisplay );
        delay( 1000 );
        // TODO: should we keep this screen up until we get the first connection? Especially since we don't know the time yet?
    }
}

void HandlePowerState( const CarIO::CarStatus& car_status )
{
#ifdef DISABLE_SLEEP
    return;
#endif
    // if IGN and Illumination are off, go to sleep.
    if( !car_status.mIgnition && !car_status.mLights )
    {
        LOG_TRACE( "Ignition and lights are off. Going to sleep." );
        Sleep();
        return;
    }

    // If IGN is gone but Illumination is ON, display lights alarm.
    if( !car_status.mIgnition && car_status.mLights )
    {
        if( !LightsAlarmActive )
        {
            LOG_TRACE( "Ignition is off, but Lights are on. Alarm" );
            LightsAlarmActive = true;
            CarIO::StartBeeper( 4, 1100, 80, 125, 1600 );
            display::DrawLightsAlarm( &gDisplay );
            gTft->DrawCanvas( &gDisplay );
        }
        return;
    }

    // If IGN is present, return to normal behavior.
    if( car_status.mIgnition )
    {
        if( LightsAlarmActive )
        {
            LOG_TRACE( "Ignition on, turning off the lights alarm." );
            LightsAlarmActive = false;
            CarIO::StopBeeper();
        }
    }
}

void Sleep()
{
    LOG_TRACE( "going to sleep..." );
    Gps::Sleep();
    gTft->EnableSleep( true );
    esp_sleep_enable_ext1_wakeup( ( 1ull << Pin::Ignition ) | ( 1ull << Pin::Illumination ), ESP_EXT1_WAKEUP_ANY_HIGH );
    Serial.flush();
    delay( 5 );
    esp_deep_sleep_start();
}

void HandleStatusUpdate( const CarIO::CarStatus& car_status )
{
    Bluetooth::SetVehicleStatus( car_status );
}


void loop()
{
    esp_task_wdt_reset();
    DebugService::HandleAssertCase();
    static uint32_t last_memory_update = millis();
    if( millis() - last_memory_update > 5000 )
    {
        last_memory_update = millis();
        PRINT_MEMORY_USAGE();
    }
    {
        auto motion_state = Motion::GetState();
        if( motion_state.mValid )
        {
            auto now = millis();
            BrakeHistoryTracker.PushData( motion_state.mForward, now );
            LateralHistoryTracker.PushData( motion_state.mLeft, now );
        }
    }
    uint32_t fw_bytes = 0;
    if( BleOta::IsInProgress( &fw_bytes ) )
    {
        if( !FwUpdateInProgress )
        {
            FwUpdateInProgress = true;
            // update the display
            LOG_TRACE( "FW Update started. Disabling normal functions." );
        }

        if( BleOta::IsRebootRequired() )
        {
            esp_restart();
            return;
        }

        if( fw_bytes >= FwBytesReceived )
        {
            FwBytesReceived = fw_bytes;
            display::OtaInProgressProps ota_screen;
            ota_screen.bytesReceived = fw_bytes;
            display::DrawOtaInProgress( &gDisplay, ota_screen );
            gTft->DrawCanvas( &gDisplay );
        }
        return; // don't do anything else while we're updating.
    }
    Bluetooth::Service();
    Gps::Service();
    // Record one GPS sample per NMEA cycle (fix or not) when recording is armed.
    // time.isUpdated() fires once per cycle and self-clears; nothing else reads
    // it, so this captures exactly one record per second.
    if( Gps::GetGps()->time.isUpdated() )
    {
        GpsRecorder::OnGpsCycle();
    }
    CarIO::Service();

    // When a new route is downloaded, auto-switch to the Navigation screen so the
    // driver sees turn-by-turn without manually cycling screens.
    if( NavigationService::ConsumeNewRoute() )
    {
        gCurrentScreen = CurrentScreen::Navigation;
        LOG_INFO( "nav: new route -> switching to Navigation screen" );
    }

    // Live navigation matcher: when a route is loaded and the GPS has a fresh
    // fix, run the matcher (~1Hz on each new fix), store the result for the
    // Navigation screen, and log it (+ timing) for road testing.
    if( NavigationService::HasRoute() )
    {
        static uint32_t last_match_loc_age_ms = 0xFFFFFFFF;
        auto* gps = Gps::GetGps();
        gNavHasFix = gps->location.isValid() && gps->location.age() < 5000;
        if( gNavHasFix )
        {
            // Only re-run when the location has updated since last time (~1Hz).
            uint32_t age = gps->location.age();
            if( age < last_match_loc_age_ms )
            {
                last_match_loc_age_ms = age;
                nav::GpsFix fix{ gps->location.lat(), gps->location.lng() };
                const auto& route = NavigationService::GetRoute();
                auto t0 = micros();
                gNavResult = nav::match( route, fix );
                auto match_us = micros() - t0;
                gNavInstruction.clear();
                if( gNavResult.nextManeuverIndex >= 0 &&
                    gNavResult.nextManeuverIndex < ( int )route.maneuvers.size() )
                {
                    gNavInstruction = route.maneuvers[ gNavResult.nextManeuverIndex ].instruction;
                }
                // Upcoming road geometry for the perspective view, anchored at the
                // matched (on-route) position so the road follows the route.
                nav::CenterlineParams cl_params;
                cl_params.aheadMeters = 200.0;
                gNavCenterline = nav::routeCenterline( route, gNavResult.projected, cl_params );
                LOG_INFO( "nav: along=%.0f off=%.1f%s toTurn=%.0f toDest=%.0f match=%uus next=\"%s\"",
                          gNavResult.distanceAlongRouteMeters, gNavResult.offRouteDistanceMeters,
                          gNavResult.isOffRoute ? " OFFROUTE" : "",
                          gNavResult.distanceToNextTurnMeters, gNavResult.distanceToDestinationMeters,
                          ( unsigned )match_us, gNavInstruction.c_str() );
            }
            else
            {
                last_match_loc_age_ms = age;
            }
        }
    }
    else
    {
        gNavHasFix = false;
    }
    auto car_status = CarIO::GetStatus();
    auto button_events = CarIO::GetButtonEvents();
    if( button_events.mHourButtonPressed )
    {
        LOG_TRACE( "hour button clicked" );
        // advance current screen by one.
        if( gCurrentScreen == CurrentScreen::Default )
        {
            gCurrentScreen = CurrentScreen::Status;
        }
        else if( gCurrentScreen == CurrentScreen::Status )
        {
            gCurrentScreen = CurrentScreen::QM;
            QuarterMile::Reset();
        }
#if ENABLE_APPLE_NOTIFICATIONS
        else if( gCurrentScreen == CurrentScreen::QM )
        {
            gCurrentScreen = CurrentScreen::Notifications;
        }
        else if( gCurrentScreen == CurrentScreen::Notifications )
        {
            gCurrentScreen = CurrentScreen::Navigation;
        }
#else
        else if( gCurrentScreen == CurrentScreen::QM )
        {
            gCurrentScreen = CurrentScreen::Navigation;
        }
#endif
        else if( gCurrentScreen == CurrentScreen::Navigation )
        {
            gCurrentScreen = CurrentScreen::GMeter;
        }
        else if( gCurrentScreen == CurrentScreen::GMeter )
        {
            gCurrentScreen = CurrentScreen::Default;
        }
    }
    if( button_events.mMinuteButtonPressed )
    {
        LOG_TRACE( "minute button clicked" );
    }
    HandlePowerState( car_status );
    HandleStatusUpdate( car_status );
    if( LightsAlarmActive )
    {
        return;
    }

    if( gCurrentScreen == CurrentScreen::Default )
    {
        // update the display with everything.
        display::ClockProps clock;
        tm time;
        if( getLocalTime( &time, 100 ) )
        {
            clock.hours24 = time.tm_hour;
            clock.minutes = time.tm_min;
        }

        if( Gps::GetGps()->speed.isValid() && Gps::GetGps()->speed.age() < 60000 )
        {
            clock.speedMph = Gps::GetGps()->speed.mph();
        }
        clock.headlight = car_status.mLights;
        clock.bluetooth = Bluetooth::IsConnected();
        const auto& media_info = AppleMediaService::GetMediaInformation();
        std::string media_title;
        if( media_info.mPlaybackState == AppleMediaService::MediaInformation::PlaybackState::Playing )
        {
            media_title = media_info.mTitle;
            clock.mediaTitle = media_title.c_str();
        }

        display::DrawClock( &gDisplay, clock );
        gTft->DrawCanvas( &gDisplay );
    }
    else if( gCurrentScreen == CurrentScreen::Status )
    {
        display::StatusProps status;
        status.batteryVolts = car_status.mBatteryVoltage;
        status.gpsHasFix = Gps::GetGps()->location.isValid();
        if( status.gpsHasFix )
        {
            status.latitude = Gps::GetGps()->location.lat();
            status.longitude = Gps::GetGps()->location.lng();
            status.speedMph = Gps::GetGps()->speed.mph();
            status.headingDegrees = Gps::GetGps()->course.deg();
        }
        else
        {
            // No fix: show acquisition diagnostics so it can be watched outdoors.
            auto dbg = Gps::GetDebug();
            status.gpsSatsInView = dbg.satsInView;
            status.gpsSatsUsed = dbg.satsUsed;
            status.gpsFixQuality = dbg.fixQuality;
            status.gpsChars = dbg.charsProcessed;
        }
        auto motion = Motion::GetState();
        if( motion.mValid )
        {
            status.forwardG = motion.mForward;
            status.lateralG = motion.mLeft;
            status.verticalG = motion.mUp;
        }
        display::DrawStatus( &gDisplay, status );
        gTft->DrawCanvas( &gDisplay );
    }
    else if( gCurrentScreen == CurrentScreen::QM )
    {
        QuarterMile::Service( &gDisplay, gTft, button_events, Gps::GetGps() );
    }
#if ENABLE_APPLE_NOTIFICATIONS
    else if( gCurrentScreen == CurrentScreen::Notifications )
    {
        AppleNotifications::NotificationSummary latest_notification;
        display::NotificationsProps notifications;
        notifications.hasNotification = NotificationProcessor::GetLatestNotification( latest_notification );
        std::string n_title = latest_notification.mTitle.value_or( "--" );
        std::string n_message = latest_notification.mMessage.value_or( "--" );
        std::string n_subtitle = latest_notification.mSubtitle.value_or( "--" );
        notifications.notification.title = n_title.c_str();
        notifications.notification.message = n_message.c_str();
        notifications.notification.subtitle = n_subtitle.c_str();
        notifications.notificationCount = NotificationProcessor::GetNotificationCount();
        display::DrawNotifications( &gDisplay, notifications );
        gTft->DrawCanvas( &gDisplay );
    }
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

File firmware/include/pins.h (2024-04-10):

#pragma once
#include <cstdint>


#define REV2
namespace Pin
{
    // TFT & SD Card
    constexpr int8_t TftReset = 15;
    constexpr int8_t TftCs = 14;
    constexpr int8_t TftDc = 21;
    constexpr int8_t TftPower = 27;
    // SPI
    constexpr int8_t Sck = 5;
    constexpr int8_t Miso = 19;
    constexpr int8_t Mosi = 18;
    // Car Pins
    constexpr int8_t Battery = 4;
    constexpr int8_t Illumination = 36;
    constexpr int8_t Ignition = 39;
    constexpr int8_t RearWindow = 34;
    constexpr int8_t Trunk = 25;
    constexpr int8_t Roof = 26;
    // Clock Pins
    constexpr int8_t Hour = 13;
    constexpr int8_t Minute = 35; //  the Feather connects pin 35 to VBAT divider.
    // Other
    constexpr int8_t Buzzer = 12; // internal boot-related pull down. Use as output only.
    // GPS
#ifdef REV2
    constexpr int8_t GpsRx = 16;
    constexpr int8_t GpsTx = 17;
#else
    // (note, these are the default I2C pins)
    constexpr int8_t GpsRx = 22;
    constexpr int8_t GpsTx = 23;
#endif
}

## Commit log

2021-08-28 big refactor. Moved the Apple Media Service and the Current Time Service into new files, and cleaned up their usage. added a readme.
2021-08-28 added a I2C OLED display. I'm about to replace it with a TFT.
2021-08-29 switched to a TFT display. Not the final display, but it's what I'll use till the real ones arrive.
2021-10-05 added hardware documents. This include the first (only) revision of the rear PCB, and the second (latest) revision of the front PCB.
    [DelSolClock.PcbDoc, DelSolClock.PrjPcb, DelSolClock.SchDoc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]
2021-10-05 lots of progress on the code, but far from the latest. Also added the assets that need to be downloaded to the ESP32.
2021-10-05 added CAD screenshot and link.
2021-10-09 power management is working as required. Added new splash screen added buzzer alarm.
2021-10-10 switched on first CI attempt.
2021-10-10 updated release tag filter. removed normal artifact creation.
2022-03-30 started new revision, this time in kicad 6! Schematic is done, parts are placed on PCB, but routing has not started yet. I do have jlcpcb setup for fabrication.
    [DelSolClock.kicad_pcb, DelSolClock.kicad_sch, DelSolClockFrontPCBOutline.dxf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]
2022-04-01 more progress on layout. Not done yet.
    [DelSolClock.kicad_pcb, DelSolClock.kicad_sch]
2022-04-06 most of routing complete, still more work to do.
    [DelSolClock.kicad_pcb]
2022-04-06 added logo, finished layout, ordered board.
    [DelSolClock.kicad_pcb]
2022-04-09 added rear PCB. Big problem: the power supply is too tall to fit in between the boards. we'll need to figure something out.
    Also, we should make it easier to power when debugging somehow. Switch and connector?
    [DelSolClock-Rear.kicad_pcb, DelSolClock-Rear.kicad_sch, DelSolClockRearPCBOutline.dxf]
2022-06-26 HW updates after testing the last prototype round. fixed PNP and NPN transistor pin mapping error (whoops) added keepouts and moved components inside of the board area. added holes for the rectangle 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
    Main remaining item is to adjust LED placement after testing.
    [12V voltage vs BATT ADC code.xlsx, DelSol-bottomkeepout-bottom-left.dxf, DelSol-bottomkeepout-bottomcenter.dxf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]
2023-04-19 just shipped the latest revision (Rev 4?)
    [DelSolClock.kicad_pcb]
2023-05-01 updated arduino code to latest, which includes new pinout for rev 4. Still lots left to do.
2023-06-21 switched over to display2. Note, main.cpp was not committed, because it broke a lot of stuff to demo the display on hardware.
    [tft.cpp]
2024-04-08 removed original altium project.
    [DelSolClock.PcbDoc, DelSolClock.PrjPcb, DelSolClock.SchDoc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]
2024-04-08 moved kicad version into hardware folder.
    [12V voltage vs BATT ADC code.xlsx, DelSol-bottomkeepout-bottom-left.dxf, DelSol-bottomkeepout-bottomcenter.dxf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]
2024-04-08 added quarter mile timer. added ability to click through screens with hour button.
2024-04-10 added a simple logger library, and converted all serial.print calls to use it.
2025-01-14 updated to KiCad 8
    [DelSolClock.kicad_pcb, DelSolClock.kicad_sch, input_divider.kicad_sch]
2025-01-14 added missing 3V3 connection to the accelerometer CS pin, to select I2C mode.
    [DelSolClock.kicad_pcb, DelSolClock.kicad_sch, input_divider.kicad_sch]
2025-05-31 add instructions and scripts, etc, to make it easy to build esp32 / arduino / platformIO support with the external 32 KHz crystal.
2025-06-02 switched to custom build of esp32-arduino & bootloader, to support external 32k crystal. did not commit the actual libs zip because it's > 300 MB, above github file size limit
2025-06-02 switched to custom build of esp32-arduino & bootloader, to support external 32k crystal.
    [partitions.csv]
2025-06-02 added apple notifications, and displays for notifications and for driving directions. It still has some bugs, but it's working!
    [main.cpp]
2025-08-27 basic device connectivity is working!
2025-08-29 notifications now keep priority notifications for an extra 5 seconds. also, directions notifications filtering was improved.
2025-08-29 added new screen for the GMeter, solved the image problem, added a pre-load, etc.
    [tft.cpp]
2025-08-29 move framework to s3
2025-08-29 fix case
2025-08-30 added scan filter, reduced timeout.
2025-08-31 Fix some of our WDT timeouts. re-calibrated the battery voltage, this time 1V to 14V. added basic debug status service, lots left to do. added missing battery voltage characteristic, that's working. 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
    [12V voltage vs BATT ADC code V2.xlsx]
2026-06-16 Add Web Bluetooth web app + Render deploy config
    A Vite + TypeScript PWA companion app for the Del Sol Clock that runs in
    Bluefy on iOS (and Chrome/Edge on desktop/Android) over Web Bluetooth, so
    no native app build/deploy is needed.
    Features (parity with the MAUI app):
    - Status: live vehicle status + battery + firmware version via notifications
    - Firmware: browse GitHub releases and flash a .bin over BLE (OTA)
    - Debug: crash-dump status/download + control commands (reboot/print/assert)
    - Demo mode: fully client-side simulation for hardware-free UI/UX iteration
    Hosting: static site on Render free tier at delsol.markgarrison.io
    (render.yaml Blueprint + webapp/DEPLOY.md). Strict CSP + securi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
2026-06-19 add reconnect button.
2026-06-21 touch up the forget button
2026-06-21 added debugging to the FW update button
2026-06-29 update all screens to respect bezel better. also update the ui designer to support bezel and include missing screens
    [main.cpp]
